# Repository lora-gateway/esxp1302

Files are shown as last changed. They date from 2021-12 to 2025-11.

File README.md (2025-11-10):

# About ESXP1302 LoRa Gateway

<p align="center">
  ESXP1302 Logo
</p>

ESXP1302 = ESP32 + SX1302.

**ESXP1302** is a low cost 8 channel LoRa gateway design, based on ESP32 platform and porting of
[SX1302\_HAL](https://github.com/Lora-net/sx1302_hal), based on the latest Version *2.1.0*.

<p align="center">
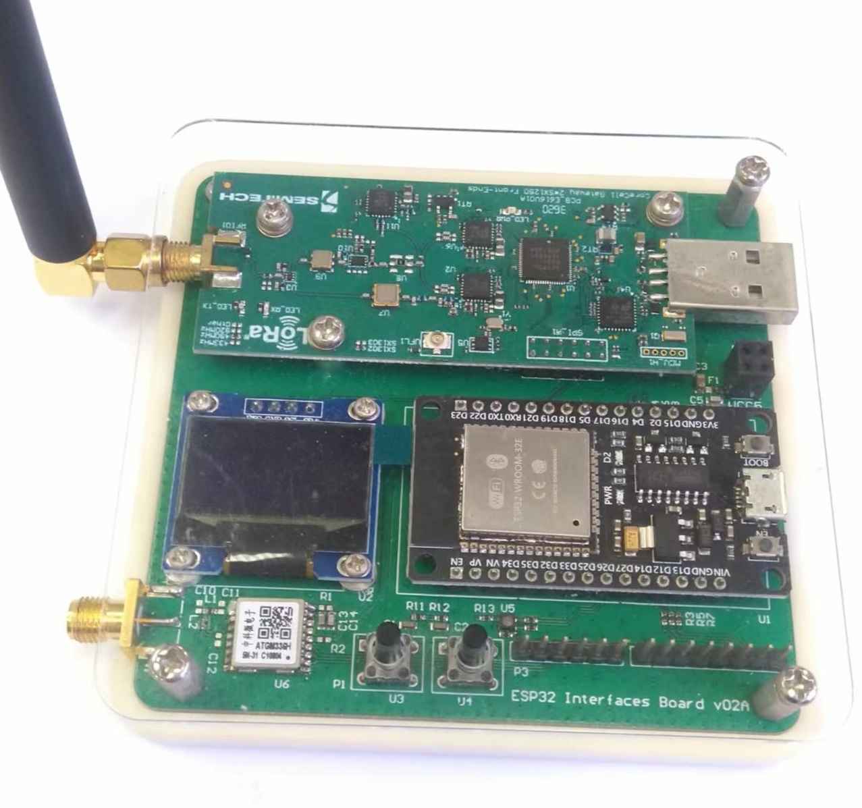
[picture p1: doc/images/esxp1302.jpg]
ESXP1302 pic
  
</p>

## How to Compile

There are two ways to compile this project.

### By PlatformIO IDE

[PlatformIO](https://platformio.org/) is a development environment that enables easy multi-platform development and centralized tooling. PlatformIO IDE bases on [Visual Studio Code](https://code.visualstudio.com/).

Follow these steps to compile ESXP1302 and flash the produced firmware.

- Clone this project with: `git clone https://github.com/lora-gateway/esxp1302`.
- Open the newly cloned folder in VS Code. If you do this for the first time, this can take quite some while as PlatformIO will download all the necessary tooling and libraries. Also if platformio is not installed, VS Code will ask you to install it.
- Open your [command palette](https://code.visualstudio.com/docs/getstarted/userinterface#_command-palette) with below shortcuts:
    - Windows/Linux: `Ctrl + Shift + P`
    - Mac: `Command + Shift + P`
- To build the firmware, simply run `PlatformIO: Build` from your command palette.
- To flash the firmware to your device, just run `PlatformIO: Upload` from your command palette.

### By Command line

You need ESP32 development environment [esp-idf](https://github.com/espressif/esp-idf).

Please follow the guide to install the SDK and the tools, or just follow below simplified steps:
```shell
git clone https://github.com/espressif/esp-idf.git
cd esp-idf
git checkout v5.5.1  # v5.4.2 also OK; other versions not verified
git submodule update --init --recursive

# below 2 steps are for Linux. For windows, use `install.bat` and `export.bat` instead.
./install.sh  # install the compilers etc.
. export.sh   # export and set up the environment
```

Then compile this project follow below steps:
```shell
git clone https://github.com/lora-gateway/esxp1302
cd esxp1302
./run_me.sh make  # compile
./run_me.sh flash_all  # flash 3 images: bootloader, partition_table and esxp1302
# ./run_me.sh flash  # use this to only flash esxp1302 firmware
```

Script `run_me.sh` can compile the code, flash the ESP32 board, and open **minicom** to monitor the output, so make sure your ESP32 board is connected.
If you are not under Linux, you need to change `run_me.sh` to use other terminal tool instead or just run your terminal tool manually.

Run `./run_me.sh -h` for its whole usage.

**Note**: a few extra steps for esp32c3 (not needed for esp32):
- run `cp sdkconfig.esp32c3 sdkconfig` before `./run_me.sh make`.
- for `./run_me.sh flash` to work, need to change `--chip esp32` to `--chip esp32c3` at line 13 in file `run_me.sh`.

## Configurations

There are 2 compile targets:
- **main/packet_forwarder/lora_pkt_fwd.c**. This is the default target.
- **main/libloragw-test/cli4test.c**. This provides a command line interface to support several test commands.

It's controlled by flag **CONFIG_LIBLORAGW_TEST**. Change the value to "1" in `run_me.sh` to switch to the second target.

## Usage

At the terminal, you should be able to input the command with your argument of option, such as:
```shell
test_loragw_hal_tx -r 1250 -c 0 -f 505.5 --pwid 22 -b 125 -n 20
test_loragw_hal_tx -r 1250 -c 0 -f 505.5 --pwid 22 -b 125 -n 20 -m CW
test_network_connection -u wireless_ssid -p wireless_password --host 192.168.1.200 --port 2000
pkt_fwd -u wireless_ssid -p wireless_password --host 192.168.1.200 --port 1680
```

Or change settings for `pkt_fwd` from browser:
<p align="center">
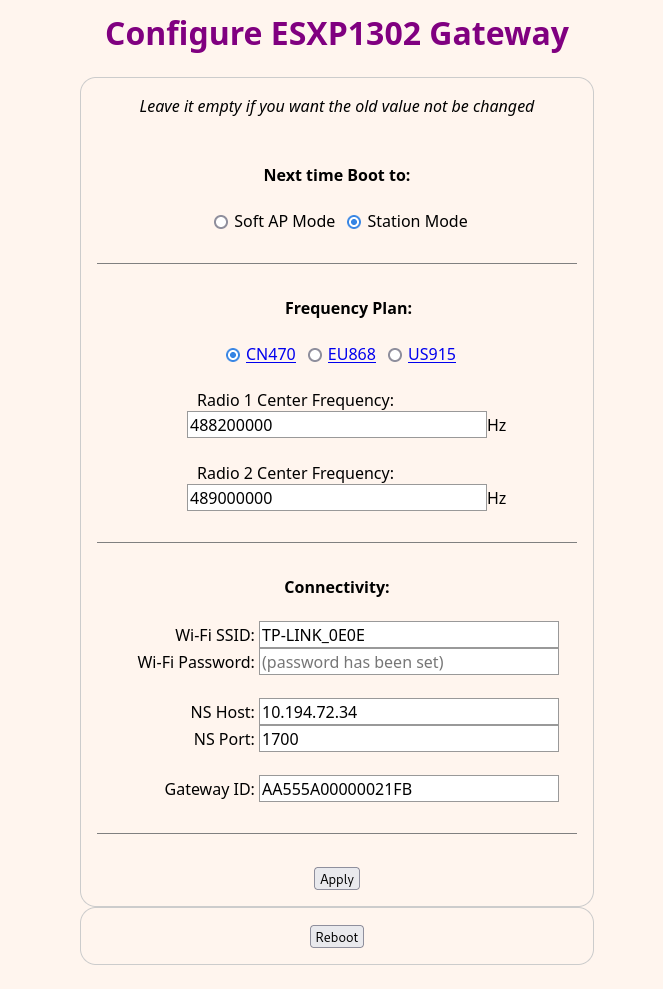
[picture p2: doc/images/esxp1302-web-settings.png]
ESXP1302 Web Settings
  
</p>

The usage details and all kinds of documents (user guide, changelog, todo list etc.) are available from `doc` folder.

## License

ESXP1302 is distributed under the 3-clause BSD license. See also [License](LICENSE.TXT).

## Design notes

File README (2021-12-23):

README

This is the ESP32 platform porting of SX1302_HAL project (https://github.com/Lora-net/sx1302_hal), based on the Version 1.0.5.
I try to stick to the original code as much as possible, but also removed some line-seperating comments I think not necessary.
And when involving ESP32 unique features, I have to invent my own way, which also imported some difference.

How to Compile

First, you need ESP32 development environment "esp-idf". You can get it from https://github.com/espressif/esp-idf.
Please follow the guide to install the SDK as well as the tools.
Below are the simplified steps for Linux platform:
```
mkdir ~/esp
cd ~/esp
git clone --recursive https://github.com/espressif/esp-idf.git
cd esp-idf
# git checkout v4.0  # optional; this is the status I used for early development
# git checkout 4a011f31  # optional; this is the status after I upgraded the esp-idf with commit '8b9050a' at 2021-12-03.
./install.sh  # install the compilers etc.
. export.sh   # export and set up the environment
```

Then you can compile this project by first change to the project folder, and use `./run_it.sh` to build and flash it.
Run `./run_it.sh -h` for its usage.
This script can compile the code, flash the ESP32 board, and open 'minicom' to monitor the output, so make sure your ESP32 board is connected.
If you are not under Linux, you need to change `run_it.sh` to use other terminal tool instead or just run your terminal tool manually.

Configurations

There are some compile targets indeed, just as under the original sx1302_hal project under "libloragw/tst/test_*".
But you have to choose only one for compilation by change the file 'main/main.c', which is a symbol link to one of test/test_* files.
The default is test/lora_pkt_fwd.c, but you can change to others such as test/test_loragw_hal_rx.c before you run 'run_it.sh'.

Usage

At the terminal, you should be able to input the command with your argument of option, such as:
```
test_loragw_hal_tx -r 1250 -c 0 -f 505.5 --pwid 22 -b 125 -n 20
test_loragw_hal_tx -r 1250 -c 0 -f 505.5 --pwid 22 -b 125 -n 20 -m CW
test_network_connection -u wireless_ssid -p wireless_password --host 192.168.1.200 --port 2000
pkt_fwd -u wireless_ssid -p wireless_password --host 192.168.1.200 --port 1680
```

Issues and TODOs

There are some issues need to be fixed, and more features under development.

Below is the list of some of them:
1. A few test targets do no work: test_loragw_cal.c, test_loragw_counter.c, test_loragw_capture_ram.c and test_loragw_gps.c.
2. GPS can output raw data with the module "ATGM336H" but hasn't been fully verified yet.
3. Configuration from web site using ESP32 Wifi as Soft AP and web server still ongoing.

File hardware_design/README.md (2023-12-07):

# Hardware Design

The hardware of ESXP1302 mainly includes 3 parts:
- SX1302 based ref design
- Motherboard connecting SX1302 and ESP32 and screen etc.
- Outside case

## SX1302 based ref design

For this part, we just re-use the ref design provided by Semtech.

It provided in this address:
    https://www.semtech.com/products/wireless-rf/lora-core/sx1302cssxxxgw1
Under "Reference Designs" --> "USB Corecell ref design for LBT Spectral Scan gateway production package for China"

The 7z file is downloaded from that place and put under "sx1302/" folder for convenient.

**Note**:
- This ref design is for CN470 frequency band. In order to support other regions, users need to modify it accordingly.
- Since esxp1302 only uses the SPI interface for communication and the USB part is not used, so such part shouldn't be soldered (which also can save some BOM cost).

## Motherboard

This is a very simple interface board used to connect other components. Besides of the SX1302 board and ESP32 board, it contains a few other parts:
- **An screen**. It is optional and used to display some helpful information (such as Wi-Fi status; NS info; time etc.).
- **A GPS chip**. This is also optional; It can provide PPS pulse which could be useful for accurate time sync, maybe can be useful for Class B (but not implemented yet).
- **2 Buttons**. They purpose of them is for choosing Wi-Fi mode when boot, and for other potential usage not implemented yet.

The design material is under "motherboard/" folder.

## Outside case

The outside case include 2 parts:
- transparent top layer
- solid white botton layer

Both parts can be 3D printed. The design material is under "case/" folder.

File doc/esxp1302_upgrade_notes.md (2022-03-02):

# Notes for ESXP1302 Gateway Upgrade

## firmware upgrade preparation

First, make sure you have `Python 3` installed in your PC. it provides the tool `pip` to install other tools.

Then you'll need `esptool` to upgrade firmware for ESXP1302. Install it with:
```shell
pip install esptool
```

If failed, try `python -m pip install esptool` or `pip3 install esptool`.

You may need `setuptools` first. You can install it with `pip install setuptools`.

Now you can check if it's ready by run `esptool.py` or `python -m esptool`.

## upgrade firmware

There are two ways to upgrade the firmware.

### Fully upgrade

You'll need to use this upgrade way if the ESP32 is never been upgraded.

Put the firmware file(s) somewhere, then run below command under that same foler for fully upgrade:
```shell
esptool.py --port /dev/ttyUSB0 --baud 921600 --chip esp32 --before default_reset --after hard_reset write_flash -z --flash_mode dio --flash_freq 40m --flash_size detect 0x10000 ESXP1302-Pkt-Fwd.bin 0x1000 bootloader.bin 0x8000 partition-table.bin
```

You may need to change the port name(`/dev/ttyUSB0`) to the right value, for example, it would be `COMx` under Windows.

### Application upgrade

The way only upgrade the Application part, mainly used to replace an older version.

The command becomes:
```shell
esptool.py --port /dev/ttyUSB0 --baud 921600 --chip esp32 --before default_reset --after hard_reset write_flash -z --flash_mode dio --flash_freq 40m --flash_size detect 0x10000 ESXP1302-Pkt-Fwd.bin
```

**Note:** If you got error as `Failed to connect to ESP32: Timed out waiting for packet header` or `Wrong boot mode detected`, then just try the upgrade command again while pressing one of the esp32's small buttons during the upgrade command running.

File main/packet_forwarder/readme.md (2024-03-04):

	 / _____)             _              | |
	( (____  _____ ____ _| |_ _____  ____| |__
	 \____ \| ___ |    (_   _) ___ |/ ___)  _ \
	 _____) ) ____| | | || |_| ____( (___| | | |
	(______/|_____)_|_|_| \__)_____)\____)_| |_|
	  (C)2019 Semtech

SX1302 packet forwarder
=======================

## 1. Introduction

The packet forwarder is a program running on the host of a Lora gateway that
forwards RF packets receive by the concentrator to a server through a IP/UDP
link, and emits RF packets that are sent by the server. It can also emit a
network-wide GPS-synchronous beacon signal used for coordinating all nodes of
the network.

To learn more about the network protocol between the gateway and the server,
please read the PROTOCOL.TXT document.

## 2. System schematic and definitions

	((( Y )))
	    |
	    |
	+- -|- - - - - - - - - - - - -+        xxxxxxxxxxxx          +--------+
	|+--+-----------+     +------+|       xx x  x     xxx        |        |
	||              |     |      ||      xx  Internet  xx        |        |
	|| Concentrator |<----+ Host |<------xx     or    xx-------->|        |
	||              | SPI |      ||      xx  Intranet  xx        | Server |
	|+--------------+     +------+|       xxxx   x   xxxx        |        |
	|   ^                    ^    |           xxxxxxxx           |        |
	|   | PPS  +-----+  NMEA |    |                              |        |
	|   +------| GPS |-------+    |                              +--------+
	|          +-----+            |
	|                             |
	|            Gateway          |
	+- - - - - - - - - - - - - - -+

Concentrator: radio RX/TX board, based on Semtech multichannel modems (SX130x),
transceivers (SX135x) and/or low-power stand-alone modems (SX127x).

Host: embedded computer on which the packet forwarder is run. Drives the
concentrator through a SPI link.

Gateway: a device composed of at least one radio concentrator, a host, some
network connection to the internet or a private network (Ethernet, 3G, Wifi,
microwave link), and optionally a GPS receiver for synchronization.

Server: an abstract computer that will process the RF packets received and
forwarded by the gateway, and issue RF packets in response that the gateway
will have to emit.

## 3. Dependencies

This program uses the Parson library (http://kgabis.github.com/parson/) by
Krzysztof Gabis for JSON parsing.
Many thanks to him for that very practical and well written library.

This program is statically linked with the libloragw Lora concentrator library.
It was tested with v1.3.0 of the library but should work with any later
version provided the API is v1 or a later backward-compatible API.
Data structures of the received packets are accessed by name (ie. not at a
binary level) so new functionalities can be added to the API without affecting
that program at all.

This program follows the v1.3 version of the gateway-to-server protocol.

The last dependency is the hardware concentrator (based on FPGA or SX130x
chips) that must be matched with the proper version of the HAL.

## 4. Usage

* Pick the global_conf.json file that fit with your platform, region and feature
need.
* Update the JSON configuration (global and local) files, as explained below.
* Run:
    ./lora_pkt_fwd -c global_conf.json

To stop the application, press Ctrl+C.
Unless it is manually stopped or encounter a critical error, the program will
run forever.

The way the program takes configuration files into account is the following:
 * if a specific configuration file is given as program argument, use the
  one specified.
 * if there is a global_conf.json parse it.

The global configuration file should be exactly the same throughout your
network, contain all global parameters (parameters for "sensor" radio
channels) and preferably default "safe" values for parameters that are
specific for each gateway (eg. specify a default MAC address).

In each configuration file, the program looks for a JSON object named
"SX130x_conf" that should contain the parameters for the Lora concentrator
board (RF channels definition, modem parameters, etc) and another JSON object
called "gateway_conf" that should contain the gateway parameters (gateway MAC
address, IP address of the server, keep-alive time, etc).

To learn more about the JSON configuration format, read the provided JSON
files and the libloragw API documentation.

Every X seconds (parameter settable in the configuration files) the program
display statistics on the RF packets received and sent, and the network
datagrams received and sent.
The program also send some statistics to the server in JSON format.

## 5. "Just-In-Time" downlink scheduling

The LoRa concentrator can have only one TX packet programmed for departure at a
time. The actual departure of a downlink packet will be done based on its
timestamp, when the concentrator internal counter reaches timestamp’s value.
The departure of a beacon will be done based on a GPS PPS event.
It may happen that, due to network variable latency, the gateway receives one
or many downlink packets from the server while a TX is already programmed in the
concentrator. The packet forwarder has to store and order incoming downlink
packets (in a queue), so that they can all be programmed in the concentrator at
the proper time and sent over the air.
Possible failures that may occur and that have to be reported to the server are:
- It is too early or too late to send a given packet
- A packet collides with another packet already queued
- A packet collides with a beacon
- TX RF parameters (frequency, power) are not supported by gateway
- Gateway’s GPS is unlocked, so cannot process Class B downlink
It is called "Just-in-Time" (JiT) scheduling, because the packet forwarder will
program a downlink or a beacon packet in the concentrator just before it has to
be sent over the air.
Another benefit of JiT is to optimize the gateway downlink capacity by avoiding
to keep the concentrator TX buffer busy for too long.

In order to achieve "Just-in-Time" scheduling, the following software elements
have been added:
- A JiT queue, with associated enqueue/peek/dequeue functions and packet
acceptance criterias. It is where downlink packets are stored, waiting to be
sent.
- A JiT thread, which regularly checks if there is a packet in the JiT queue
ready to be programmed in the concentrator, based on current concentrator
internal time.

### 5.1. Concentrator vs GPS time synchronization

There are 2 cases for which we need to convert a GPS time to concentrator
counter:
    - Class B downlink: when the “time” field of JSON “txpk” is filled instead
      of the “tmst” field, we need to be able to determine if the packet can be
      queued in JiT queue or not, based on its corresponding concentrator
      counter value.
      Note: even if a Class-B downlink is given with a GPS timestamp, the
      concentrator TX mode is configured as “TIMESTAMP”, and not “ON_GPS”. So
      at the end, it is the counter value which will be used for transmission.
    - Beacons: beacons transmission time is based on GPS clock, and the
      concentrator TX mode is configured as “ON_GPS” for accurate beacon
      transmission on GPS PPS event. In this case, the concentrator does not
      need the packet counter to be set. But, as the JiT thread decides if a
      packet has to be peeked or not, based on its concentrator counter, we need
      to have the beacon packet counter set (see next chapter for more details
      on JiT scheduling).
We also need to convert a SX1302 counter value to GPS UTC time when we receive
an uplink, in order to fill the “time” field of JSON “rxpk” structure.

### 5.2. TX scheduling

The JiT queue implemented is a static array of nodes, where each node contains:
    - the downlink packet, with its type (beacon, downlink class A, B or C)
    - a “pre delay” which depends on packet type (BEACON_GUARD, TX_START_DELAY…)
    - a “post delay” which depends on packet type (“time on air” of this packet
      computed based on its size, datarate and coderate, or BEACON_RESERVED)

Several functions are implemented to manipulate this queue or get info from it:
    - init: initialize array with default values
    - is full / is empty: gives queue status
    - enqueue: checks if the given packet can be queued or not, based on several
      criteria’s
    - peek: checks if the queue contains a packet that must be passed
      immediately to the concentrator for transmission and returns corresponding
      index if any.
    - dequeue: actually removes from the queue the packet at index given by peek
      function

The queue is always kept sorted on ascending timestamp order.

The JiT thread will regularly check in the JiT queue if there is a packet to be
sent soon.  If a packet is matching, it is dequeued and programmed in the
concentrator TX buffer.

### 5.3. Fine tuning parameters

There are few parameters of the JiT queue which could be tweaked to adapt to
different system constraints.

    - inc/jitqueue.h:
        JIT_QUEUE_MAX: The maximum number of nodes in the queue.
    - src/jitqueue.c:
        TX_JIT_DELAY: The number of milliseconds a packet is programmed in the
                      concentrator TX buffer before its actual departure time.
        TX_MARGIN_DELAY: Packet collision check margin

### 6. License

Copyright (C) 2019, SEMTECH S.A.
All rights reserved.

Redistribution and use in source and binary forms, with or without
modification, are permitted provided that the following conditions are met:

* Redistributions of source code must retain the above copyright
  notice, this list of conditions and the following disclaimer.
* Redistributions in binary form must reproduce the above copyright
  notice, this list of conditions and the following disclaimer in the
  documentation and/or other materials provided with the distribution.
* Neither the name of the Semtech corporation nor the
  names of its contributors may be used to endorse or promote products
  derived from this software without specific prior written permission.

THIS SOFTWARE IS PROVIDED BY THE COPYRIGHT HOLDERS AND CONTRIBUTORS "AS IS" AND
ANY EXPRESS OR IMPLIED WARRANTIES, INCLUDING, BUT NOT LIMITED TO, THE IMPLIED
WARRANTIES OF MERCHANTABILITY AND FITNESS FOR A PARTICULAR PURPOSE ARE
DISCLAIMED. IN NO EVENT SHALL SEMTECH S.A. BE LIABLE FOR ANY
DIRECT, INDIRECT, INCIDENTAL, SPECIAL, EXEMPLARY, OR CONSEQUENTIAL DAMAGES
(INCLUDING, BUT NOT LIMITED TO, PROCUREMENT OF SUBSTITUTE GOODS OR SERVICES;
LOSS OF USE, DATA, OR PROFITS; OR BUSINESS INTERRUPTION) HOWEVER CAUSED AND
ON ANY THEORY OF LIABILITY, WHETHER IN CONTRACT, STRICT LIABILITY, OR TORT
(INCLUDING NEGLIGENCE OR OTHERWISE) ARISING IN ANY WAY OUT OF THE USE OF THIS
SOFTWARE, EVEN IF ADVISED OF THE POSSIBILITY OF SUCH DAMAGE.

#### 7. License for Parson library

Parson ( http://kgabis.github.com/parson/ )
Copyright (C) 2012 Krzysztof Gabis

Permission is hereby granted, free of charge, to any person obtaining a copy
of this software and associated documentation files (the "Software"), to deal
in the Software without restriction, including without limitation the rights
to use, copy, modify, merge, publish, distribute, sublicense, and/or sell
copies of the Software, and to permit persons to whom the Software is
furnished to do so, subject to the following conditions:

The above copyright notice and this permission notice shall be included in
all copies or substantial portions of the Software.

THE SOFTWARE IS PROVIDED "AS IS", WITHOUT WARRANTY OF ANY KIND, EXPRESS OR
IMPLIED, INCLUDING BUT NOT LIMITED TO THE WARRANTIES OF MERCHANTABILITY,
FITNESS FOR A PARTICULAR PURPOSE AND NONINFRINGEMENT. IN NO EVENT SHALL THE
AUTHORS OR COPYRIGHT HOLDERS BE LIABLE FOR ANY CLAIM, DAMAGES OR OTHER
LIABILITY, WHETHER IN AN ACTION OF CONTRACT, TORT OR OTHERWISE, ARISING FROM,
OUT OF OR IN CONNECTION WITH THE SOFTWARE OR THE USE OR OTHER DEALINGS IN
THE SOFTWARE.

*EOF*

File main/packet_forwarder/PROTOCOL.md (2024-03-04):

	  ______                              _
	 / _____)             _              | |
	( (____  _____ ____ _| |_ _____  ____| |__
	 \____ \| ___ |    (_   _) ___ |/ ___)  _ \
	 _____) ) ____| | | || |_| ____( (___| | | |
	(______/|_____)_|_|_| \__)_____)\____)_| |_|
	  (C)2019 Semtech

Basic communication protocol between LoRa gateway and Network Server
====================================================================

## 1. Introduction

The protocol between the gateway and the server is purposefully very basic and
for demonstration purpose only, or for use on private and reliable networks.

There is no authentication of the gateway or the server, and the acknowledges
are only used for network quality assessment, not to correct UDP datagrams
losses (no retries).

## 2. System schematic and definitions

	 ((( Y )))
	     |
	     |
	+ - -|- - - - - - - - - - - - - +        xxxxxxxxxxxx          +--------+
	| +--+-----------+     +------+ |       xx x  x     xxx        |        |
	| |              |     |      | |      xx  Internet  xx        |        |
	| | Concentrator |<--->| Host |<-------xx     or    xx-------->|        |
	| |              | SPI |      | |      xx  Intranet  xx        | Server |
	| +--------------+     +------+ |       xxxx   x   xxxx        |        |
	|    ^                     ^    |           xxxxxxxx           |        |
	|    | PPS +-------+ NMEA  |    |                              |        |
	|    +-----|  GPS  |-------+    |                              +--------+
	|          | (opt) |            |
	|          +-------+            |
	|                               |
	|             Gateway           |
	+- - - - - - - - - - - - - - - -+

__Concentrator__: radio RX/TX board, based on Semtech multichannel modems
(SX130x), transceivers (SX125x) and/or low-power stand-alone modems (SX127x).

__Host__: embedded computer on which the packet forwarder is run. Drives the
concentrator through a SPI link.

__GPS__: GNSS (GPS, Galileo, GLONASS, etc) receiver with a "1 Pulse Per Second"
output and a serial link to the host to send NMEA frames containing time and
geographical coordinates data. Optional.

__Gateway__: a device composed of at least one radio concentrator, a host, some
network connection to the internet or a private network (Ethernet, 3G, Wifi,
microwave link), and optionally a GPS receiver for synchronization.

__Server__: an abstract computer that will process the RF packets received and
forwarded by the gateway, and issue RF packets in response that the gateway
will have to emit.

It is assumed that the gateway can be behind a NAT or a firewall stopping any
incoming connection.
It is assumed that the server has an static IP address (or an address solvable
through a DNS service) and is able to receive incoming connections on a
specific port.

## 3. Upstream protocol

### 3.1. Sequence diagram ###

	+---------+                                                    +---------+
	| Gateway |                                                    | Server  |
	+---------+                                                    +---------+
	     | -----------------------------------\                         |
	     |-| When 1-N RF packets are received |                         |
	     | ------------------------------------                         |
	     |                                                              |
	     | PUSH_DATA (token X, GW MAC, JSON payload)                    |
	     |------------------------------------------------------------->|
	     |                                                              |
	     |                                           PUSH_ACK (token X) |
	     |<-------------------------------------------------------------|
	     |                              ------------------------------\ |
	     |                              | process packets *after* ack |-|
	     |                              ------------------------------- |
	     |                                                              |

### 3.2. PUSH_DATA packet ###

That packet type is used by the gateway mainly to forward the RF packets
received, and associated metadata, to the server.

 Bytes  | Function
:------:|---------------------------------------------------------------------
 0      | protocol version = 2
 1-2    | random token
 3      | PUSH_DATA identifier 0x00
 4-11   | Gateway unique identifier (MAC address)
 12-end | JSON object, starting with {, ending with }, see section 4

### 3.3. PUSH_ACK packet ###

That packet type is used by the server to acknowledge immediately all the
PUSH_DATA packets received.

 Bytes  | Function
:------:|---------------------------------------------------------------------
 0      | protocol version = 2
 1-2    | same token as the PUSH_DATA packet to acknowledge
 3      | PUSH_ACK identifier 0x01

## 4. Upstream JSON data structure

The root object can contain an array named "rxpk":

``` json
{
	"rxpk":[ {...}, ...]
}
```

That array contains at least one JSON object, each object contain a RF packet
and associated metadata with the following fields:

 Name |  Type  | Function
:----:|:------:|--------------------------------------------------------------
 time | string | UTC time of pkt RX, us precision, ISO 8601 'compact' format
 tmms | number | GPS time of pkt RX, number of milliseconds since 06.Jan.1980
 tmst | number | Internal timestamp of "RX finished" event (32b unsigned)
 ftime| number | fine timestamp, number of nanoseconds since last PPS [0..999999999] (Optional)
 freq | number | RX central frequency in MHz (unsigned float, Hz precision)
 chan | number | Concentrator "IF" channel used for RX (unsigned integer)
 rfch | number | Concentrator "RF chain" used for RX (unsigned integer)
 mid  | number | Concentrator modem ID on which pkt has been received
 stat | number | CRC status: 1 = OK, -1 = fail, 0 = no CRC
 modu | string | Modulation identifier "LORA" or "FSK"
 datr | string | LoRa datarate identifier (eg. SF12BW500)
 datr | number | FSK datarate (unsigned, in bits per second)
 codr | string | LoRa ECC coding rate identifier
 rssi | number | RSSI of the channel in dBm (signed integer, 1 dB precision)
 rssis| number | RSSI of the signal in dBm (signed integer, 1 dB precision)
 lsnr | number | Lora SNR ratio in dB (signed float, 0.1 dB precision)
 foff | number | LoRa frequency offset in Hz (signed interger)
 size | number | RF packet payload size in bytes (unsigned integer)
 data | string | Base64 encoded RF packet payload, padded

Example (white-spaces, indentation and newlines added for readability):

``` json
{"rxpk":[
	{
		"tmst":3512348611,
		"time":"2020-10-01T09:30:52.592567Z",
		"tmms":1285579871592,
		"ftime":85224290,
		"chan":2,
		"rfch":0,
		"freq":866.349812,
		"mid":3,
		"stat":1,
		"modu":"LORA",
		"datr":"SF7BW125",
		"codr":"4/6",
		"rssi":-35,
		"lsnr":5.1,
		"foff":-3313,
		"size":32,
		"data":"-DS4CGaDCdG+48eJNM3Vai-zDpsR71Pn9CPA9uCON84"
	},{
		"time":"2013-03-31T16:21:17.530974Z",
		"tmst":3512348514,
		"chan":9,
		"rfch":1,
		"freq":869.1,
		"stat":1,
		"modu":"FSK",
		"datr":50000,
		"rssi":-75,
		"size":16,
		"data":"VEVTVF9QQUNLRVRfMTIzNA=="
	},{
		"time":"2013-03-31T16:21:17.532038Z",
		"tmst":3316387610,
		"chan":0,
		"rfch":0,
		"freq":863.00981,
		"stat":1,
		"modu":"LORA",
		"datr":"SF10BW125",
		"codr":"4/7",
		"rssi":-38,
		"lsnr":5.5,
		"size":32,
		"data":"ysgRl452xNLep9S1NTIg2lomKDxUgn3DJ7DE+b00Ass"
	}
]}
```

The root object can also contain an object named "stat" :

``` json
{
	"rxpk":[ {...}, ...],
	"stat":{...}
}
```

It is possible for a packet to contain no "rxpk" array but a "stat" object.

``` json
{
	"stat":{...}
}
```

That object contains the status of the gateway, with the following fields:

 Name |  Type  | Function
:----:|:------:|--------------------------------------------------------------
 time | string | UTC 'system' time of the gateway, ISO 8601 'expanded' format
 lati | number | GPS latitude of the gateway in degree (float, N is +)
 long | number | GPS latitude of the gateway in degree (float, E is +)
 alti | number | GPS altitude of the gateway in meter RX (integer)
 rxnb | number | Number of radio packets received (unsigned integer)
 rxok | number | Number of radio packets received with a valid PHY CRC
 rxfw | number | Number of radio packets forwarded (unsigned integer)
 ackr | number | Percentage of upstream datagrams that were acknowledged
 dwnb | number | Number of downlink datagrams received (unsigned integer)
 txnb | number | Number of packets emitted (unsigned integer)
 temp | number | Current temperature in degree celcius (float)

Example (white-spaces, indentation and newlines added for readability):

``` json
{"stat":{
    "time":"2014-01-12 08:59:28 GMT",
    "lati":46.24000,
    "long":3.25230,
    "alti":145,
    "rxnb":2,
    "rxok":2,
    "rxfw":2,
    "ackr":100.0,
    "dwnb":2,
    "txnb":2,
    "temp": 23.2
}}
```

## 5. Downstream protocol

### 5.1. Sequence diagram ###

	+---------+                                                    +---------+
	| Gateway |                                                    | Server  |
	+---------+                                                    +---------+
	     | -----------------------------------\                         |
	     |-| Every N seconds (keepalive time) |                         |
	     | ------------------------------------                         |
	     |                                                              |
	     | PULL_DATA (token Y, MAC@)                                    |
	     |------------------------------------------------------------->|
	     |                                                              |
	     |                                           PULL_ACK (token Y) |
	     |<-------------------------------------------------------------|
	     |                                                              |

	+---------+                                                    +---------+
	| Gateway |                                                    | Server  |
	+---------+                                                    +---------+
	     |      ------------------------------------------------------\ |
	     |      | Anytime after first PULL_DATA for each packet to TX |-|
	     |      ------------------------------------------------------- |
	     |                                                              |
	     |                            PULL_RESP (token Z, JSON payload) |
	     |<-------------------------------------------------------------|
	     |                                                              |
	     | TX_ACK (token Z, JSON payload)                               |
	     |------------------------------------------------------------->|

### 5.2. PULL_DATA packet ###

That packet type is used by the gateway to poll data from the server.

This data exchange is initialized by the gateway because it might be
impossible for the server to send packets to the gateway if the gateway is
behind a NAT.

When the gateway initialize the exchange, the network route towards the
server will open and will allow for packets to flow both directions.
The gateway must periodically send PULL_DATA packets to be sure the network
route stays open for the server to be used at any time.

 Bytes  | Function
:------:|---------------------------------------------------------------------
 0      | protocol version = 2
 1-2    | random token
 3      | PULL_DATA identifier 0x02
 4-11   | Gateway unique identifier (MAC address)

### 5.3. PULL_ACK packet ###

That packet type is used by the server to confirm that the network route is
open and that the server can send PULL_RESP packets at any time.

 Bytes  | Function
:------:|---------------------------------------------------------------------
 0      | protocol version = 2
 1-2    | same token as the PULL_DATA packet to acknowledge
 3      | PULL_ACK identifier 0x04

### 5.4. PULL_RESP packet ###

That packet type is used by the server to send RF packets and associated
metadata that will have to be emitted by the gateway.

 Bytes  | Function
:------:|---------------------------------------------------------------------
 0      | protocol version = 2
 1-2    | random token
 3      | PULL_RESP identifier 0x03
 4-end  | JSON object, starting with {, ending with }, see section 6

### 5.5. TX_ACK packet ###

That packet type is used by the gateway to send a feedback to the server
to inform if a downlink request has been accepted or rejected by the gateway.
The datagram may optionnaly contain a JSON string to give more details on
acknoledge. If no JSON is present (empty string), this means than no error
occured.

 Bytes  | Function
:------:|---------------------------------------------------------------------
 0      | protocol version = 2
 1-2    | same token as the PULL_RESP packet to acknowledge
 3      | TX_ACK identifier 0x05
 4-11   | Gateway unique identifier (MAC address)
 12-end | [optional] JSON object, starting with {, ending with }, see section 6

## 6. Downstream JSON data structure

The root object of PULL_RESP packet must contain an object named "txpk":

``` json
{
	"txpk": {...}
}
```

That object contain a RF packet to be emitted and associated metadata with the
following fields:

 Name |  Type  | Function
:----:|:------:|--------------------------------------------------------------
 imme | bool   | Send packet immediately (will ignore tmst & tmms)
 tmst | number | Send packet on a certain timestamp value (will ignore tmms)
 tmms | number | Send packet at a certain GPS time (GPS synchronization required)
 freq | number | TX central frequency in MHz (unsigned float, Hz precision)
 rfch | number | Concentrator "RF chain" used for TX (unsigned integer)
 powe | number | TX output power in dBm (unsigned integer, dBm precision)
 modu | string | Modulation identifier "LORA" or "FSK"
 datr | string | LoRa datarate identifier (eg. SF12BW500)
 datr | number | FSK datarate (unsigned, in bits per second)
 codr | string | LoRa ECC coding rate identifier
 fdev | number | FSK frequency deviation (unsigned integer, in Hz)
 ipol | bool   | Lora modulation polarization inversion
 prea | number | RF preamble size (unsigned integer)
 size | number | RF packet payload size in bytes (unsigned integer)
 data | string | Base64 encoded RF packet payload, padding optional
 ncrc | bool   | If true, disable the CRC of the physical layer (optional)
 nhdr | bool   | If true, disable the header of the physical layer (optional)

Most fields are optional.
If a field is omitted, default parameters will be used.

Examples (white-spaces, indentation and newlines added for readability):

``` json
{"txpk":{
	"imme":true,
	"freq":864.123456,
	"rfch":0,
	"powe":14,
	"modu":"LORA",
	"datr":"SF11BW125",
	"codr":"4/6",
	"ipol":false,
	"size":32,
	"data":"H3P3N2i9qc4yt7rK7ldqoeCVJGBybzPY5h1Dd7P7p8v"
}}
```

``` json
{"txpk":{
	"imme":true,
	"freq":861.3,
	"rfch":0,
	"powe":12,
	"modu":"FSK",
	"datr":50000,
	"fdev":3000,
	"size":32,
	"data":"H3P3N2i9qc4yt7rK7ldqoeCVJGBybzPY5h1Dd7P7p8v"
}}
```

In case of error or warning, the root object of TX_ACK packet must contain an
object named "txpk_ack":

``` json
{
	"txpk_ack": {...}
}
```

That object contain status information concerning the associated PULL_RESP packet.

 Name |  Type  | Function
:----:|:------:|-----------------------------------------------------------------------------------------
error | string | Indicates the type of failure that occurred for downlink request (optional)
warn  | string | Indicates that downlink request has been accepted with limitation (optional)
value | string | When a warning is raised, it gives indications about the limitation (optional)
value | number | When a warning is raised, it gives indications about the limitation (optional)

The possible values of the "error" field are:

 Value             | Definition
:-----------------:|---------------------------------------------------------------------
 TOO_LATE          | Rejected because it was already too late to program this packet for downlink
 TOO_EARLY         | Rejected because downlink packet timestamp is too much in advance
 COLLISION_PACKET  | Rejected because there was already a packet programmed in requested timeframe
 COLLISION_BEACON  | Rejected because there was already a beacon planned in requested timeframe
 TX_FREQ           | Rejected because requested frequency is not supported by TX RF chain
 GPS_UNLOCKED      | Rejected because GPS is unlocked, so GPS timestamp cannot be used

The possible values of the "warn" field are:

 Value             | Definition
:-----------------:|---------------------------------------------------------------------
 TX_POWER          | The requested power is not supported by the gateway, the power actually used is given in the value field

Examples (white-spaces, indentation and newlines added for readability):

``` json
{"txpk_ack":{
	"error":"COLLISION_PACKET"
}}
```

``` json
{"txpk_ack":{
	"warn":"TX_POWER",
    "value":20
}}
```

## 7. Revisions

### v1.6 ###
* Added "mid" field in "rxpk" for concentrator modem ID used to demodulate pkt
* Added "foff" field in "rxpk" for frequency offset measured
* Added "rssis" field in "rxpk" for signal RSSI measured.
* Added "ftime" field in "rxpk" for fine timestamping

### v1.5 ###
* Moved TX_POWER from "error" category to "warn" category in "txpk_ack" object

### v1.4 ###
* Added "tmms" field for GPS time as a monotonic number of milliseconds
ellapsed since January 6th, 1980 (GPS Epoch). No leap second.

### v1.3 ###

* Added downlink feedback from gateway to server (PULL_RESP -> TX_ACK)

### v1.2 ###

* Added value of FSK bitrate for upstream.
* Added parameters for FSK bitrate and frequency deviation for downstream.

### v1.1 ###

* Added syntax for status report JSON object on upstream.

### v1.0 ###

* Initial version.

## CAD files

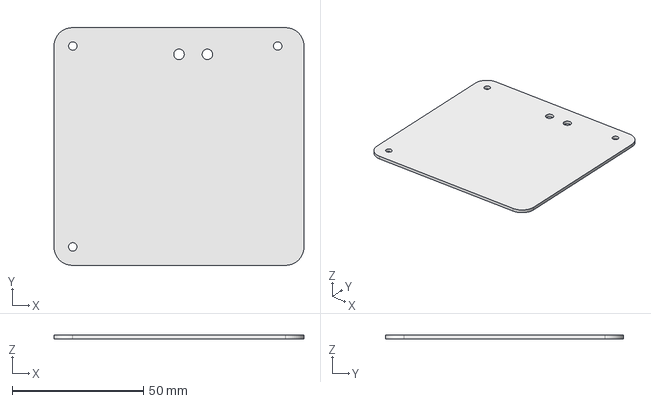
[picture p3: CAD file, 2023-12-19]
hardware_design/case/esxp1302_top_case.FCStd
95.2 x 90.5 x 1.50 mm

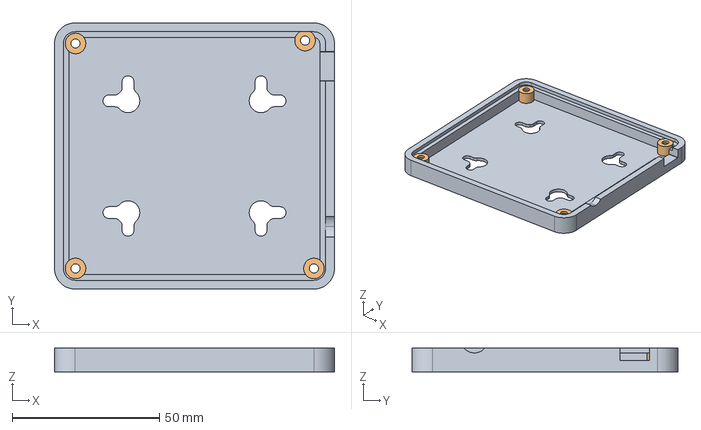
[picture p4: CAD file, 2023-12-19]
hardware_design/case/esxp1302_bottom_case.FCStd
95.2 x 90.5 x 8.00 mm
Main with Space
Columns with Holes

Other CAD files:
hardware_design/case/esxp1302_bottom_case.stl
hardware_design/case/esxp1302_top_case.dxf

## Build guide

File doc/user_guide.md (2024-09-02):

# ESXP1302 Gateway User Guide

## Basic Introduction

**ESXP1302 Gateway** project is based on `SX1302_HAL` project, but uses ESP32 instead of Raspberry Pi. *ESXP1302* = *ESP32* + *SX1302*.

This document is a very simple guide about how to configure and use ESXP1302 gateway based on **version 0.7.0**.

First, please be noted that ESXP1302 gateway has 2 types of Wi-Fi working modes, and 2 ways to configure it.

The 2 Wi-Fi modes are:
- **Soft AP** mode. The gateway works as an Wi-Fi Soft AP, so user can connect to it directly and configure it.
- **Station** mode. The gateway needs to connect to the same Wi-Fi router as the user and use that router for LoRaWAN uplink and downlink.

The 2 configuration ways are:
- **Web UI**. User can change gateway settings by browser after connect to the gateway.
- **Command line** (or Serial Port). There is a simple interactive command line interface available from the USB port, so user can configure the gateway that way without any network connection required.

## Configuration based on Wi-Fi mode

By default, the gateway boots to the Soft AP mode for the first time. It switches modes when necessary such as Wi-Fi disconnected or be controlled by user. But you can always specify which mode it boots into: just keep one of the Interface board buttons pressed during the poweron: Left button for Soft AP mode, while right button for Station mode.

In the Soft AP mode, user can connect the gateway by Wi-Fi. All the useful information can be seen from the screen, which is: `IP = "192.168.4.1"`; `username = esp32`; `password = esp32wifi`.

Now user can access the web UI by browser with address: `http://192.168.4.1`. Please be noted that the protocol is **http**, not **https**. The default login information are: `username = iot`; `password = lora`.

If the gateway boots to Station mode, then both the gateway and user needs to connect to the same wireless router. Then the only difference is user needs to get the right IP address showing on the screen or provided by the router, and access the web UI with that IP address. It **won't** be the "192.168.4.1" any more.

There are also some Wi-Fi mode automatic switch if some events happens:
- In Soft AP mode, if no changes to the web UI and no input to the command line, it reboots to Station mode in 10 minutes.
- If gateway boots to Station mode, but can't connect to wireless router (maybe wrong Wi-Fi settings or haven't set Wi-Fi yet), then it reboots to Soft AP mode in 5 minutes.
- If during the Station mode, `pkt_fwd` works all right for some time, then Wi-Fi disconnected, the gateway will try to re-connect to Wi-Fi for 5 minutes. If succeeds during that time, nothing happens; but if failed, then reboots to Soft AP mode.
- If after power on, the gateway reboots again by `brownout`, then it changes to the other mode. So user should check the screen or the command line output to be sure which mode the gateway is really in.

## Configuration by web UI

From web UI, user can configure below items:
- **next time boot into**. Generally after the configuration is done, the gateway should boot into station mode. But if the gateway will boot somewhere with some unknown Wi-Fi router and needs to provide the SSID informatioin again, then boots into Soft AP mode maybe make more sense. Consider you can always control which mode boots into by the hardware button, this option only becomes important when you can't access the gateway hardware easily.
- **Frequency Plan**. You need to choose this wisely based on your region and node settings. You can click each of them to know the details of the original JSON file used for that frequency plan.
- **Radio 1 and Radio 2 center frequency**. These 2 values should be the reasonable values based on the Frequency plan. Each control the frequency bands. The frequency bands has offsets of -300K/-100K/100K/300K Hz with the center frequency for CN470, while it's -400K/-200K/0K/200K for EU868. So please check the Frequency plan link to be sure.
- **Wi-Fi SSID and password**. Please noted that both only support the ASCII characters. It doesn't work if your SSID or password contains other UTF-8 characters such as Chinese characters. This limitation is hard to remove so you may have to change your Wi-Fi router settings.
- **NS Host and Port**. Here user needs to provide the right NS IP address (or domain name) and port.
- **Gateway ID**. Each gateway needs to have its own unique ID, so provide it here to avoid using the same one as other gateway.

If you think the original value is correct for any of above fields, then you can just leave it empty. Any value you provided would be used to replace the original one from the JSON template file.

You can save your configurations whenever you like by clicking the **Apply** button. Such changes are saved in the gateway but won't apply to the current *packet-forward* process yet. It only happens after you click the **Reboot** button to reboot the gateway, or by user reboot the gateway by power off and on.

If you don't like the default dark theme, you can try the light theme by accessing `http://<gateway_ip>/w` instead.

## Configuration by command line

If you power on the gateway by connecting the micro USB cable to a PC, then you have access to its command line interface. Use any terminal tool such as `sscom` or `putty` to access it with configuration as: **115200-8-N-1**.

The command line is the same thing as the serial port, so it outputs gateway logs. When the *packet_forward* is running, the output would mix with any characters input by user. However, if the user ignores that and continues to input or delete characters, the command line will flush itself, so it is still usable. 

When the *packet_forward* doesn't run for reasons such as when Wi-Fi is not connected, then the command line looks like a regular Linux shell interactive window; it even supports basic readline shortcuts such as `Ctrl-A` and `Ctrl-W` etc.

So far, this interface only supports one command named `pkt_fwd`. You can input `pkt_fwd -h` to learn all the options it supports, which, let's be honest, not much. It supports only parts of all the configurations available from web UI. Here is the output of `pkt_fwd -h`:
```
 ---- pkt_fwd ----

Available options:
 -h                   print this help
 -u <wifi ssid>       Wifi SSID
 -p <wifi password>   Wifi Password
 --host <NS Host>     NS Host
 --port <NS Port>     NS Port
 --gwid <gateway id>  Gateway ID
```

So, if you need to change other configuration items, please use the web UI way.

**Note:**
- Whenever you provide a valid option to `pkt_fwd`, it's saved and the gateway will reboot to apply the new changes.
- To input whitespace in command line (such as for Wi-Fi password, use `\` to escape. For example: `pkt_fwd -u mywifi -p my\ password`.

### install Windows Driver

To access the command line under Windows, users would need to install the right device driver first.

Below is the list of USB to serial converter chips installed on most of the ESP32 boards produced by Espressif together with links to the drivers:

- CP210x: [CP210x USB to UART Bridge VCP Drivers](https://www.silabs.com/developers/usb-to-uart-bridge-vcp-drivers)
- FTDI: [FTDI Virtual COM Port Drivers](https://ftdichip.com/drivers/vcp-drivers)

User can blindly install both drivers, or identifies the USB-to-UART bridge on the ESP32 board first and chooses the right one.

One way to identify the bridge under Linux is using the `lsusb` command. Run it would give output similar as **Bus 002 Device 027: ID 10c4:ea60 Silicon Labs `CP210x` UART Bridge** or **Bus 002 Device 025: ID 1a86:7523 QinHeng Electronics `CH340` serial converter**.

## Other Useful Documents

For other useful information, please refer to other documents included in the project, include the `README.md`, and a few others located in the folder `doc` including `esxp1302_upgrade_notes.md`, `notes_tips.md` and `todo_issue_list.md`.

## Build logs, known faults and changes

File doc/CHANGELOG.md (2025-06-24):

# CHANGE LOG

## v0.9.0:
- upgrade to sx1302_hal v2.1.0
- support nodo board
- add option to set NTP server address
- extends us915 TX frequency to cover the range of AS923
- allow up to 1.5MB app size
- remove black web theme
- other fixes to make esxp1302 be more flexible for different hardware designs.

## v0.8.0:
- add hardware reference design materials
- add support for esp32c3
- add support for compiling using PlatformIO
- add support for compiling under Windows (based on PlatformIO)
- optimize memory usage
- update scripts to Python3
- other fixes and document improvement

## v0.7.0:
- show version info in the screen
- change CN470 tx_freq_min from 500MHz to 470MHz for supporting RP2
- fix the bug that ns host can't be domain name
- change web username/password as 'iot/lora'
- add upgrader.py to simplify upgrade the firmware
- add license info

## v0.6.2:
- disable gps output
- workaround to support sx1303

## v0.6.1:
- hide wifi password

## v0.6.0:
- the first public released version
- add version info in the serial port output
- documents

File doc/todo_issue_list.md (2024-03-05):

# Todo List

Below are potential improvements (contributions are welcome):

- A simple online user guide (just a page linked to the web UI).
- improve the safety of Wifi by encrypting both ssid and password.
- Support user to reset both the username/password of the web UI login and for Soft AP mode.
- Reset to default: can reset the web UI and Soft AP mode username/password, as well as clean all the configs.
- Provide an online help and can be accessed from the web UI.
- Provide a way to import json file (either from web UI or some other way).
- GPS can output raw data with the module **ATGM336H** but hasn't been fully verified yet.
- Verify/update/merge test code under `main/libloragw-test/` and `main/test`.

# Issue List

Below are limitations or issues of the gateway:

- Wifi username and password only work with ASCII characters, doesn't support other UTF-8 characters.

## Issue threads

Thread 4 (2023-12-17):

Add miniPCIe interface to the board design?

danielkucera, 2023-12-17:
Hello,

I am successfully using this firmware with [LR1302 from Elecrow](https://www.elecrow.com/lr1302-lorawan-gateway-module-spi-eu868-sx1302-long-range-gateway-module-support-8-channels.html) and my [miniPCIe breakout board](https://lectronz.com/products/minipci-e-breakout-board).
This is my current setup.

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

Would you consider adding miniPCIe connector to your current HW design according to [this spec](https://www.elecrow.com/wiki/index.php?title=LR1302_LoRaWAN_Gateway_Module#Interface_Function)?
I tested the same setup also for [RAK2287](https://docs.rakwireless.com/Product-Categories/WisLink/RAK2287/Datasheet/#pinout-description) and it works .

I was considering doing it myself but I don't have the design software to edit your project and I am lazy to design it from scratch.

lora-gateway, 2023-12-18:
@danielkucera:
Thanks for this proposal. Since the market already has some miniPCIe based modules available, it would be easier for people to have the hardware ready to play with.

First, I'd like to check if all of them (or most of them) follow the same spec; then I plan to create an interface board to bridge the miniPCIe connector to the motherboard. I need help from a friend to do this, so it would take some time.

BTW: What's your design software? Is it KiCAD? Maybe in the future, someone can help to convert the hardware design to such tool so more people can modify directly...

danielkucera, 2023-12-18:
Thanks for the reply. Yes, I prefer KiCad. I even managed to import the board design and I am trying to add the interface.
This is my current WiP:
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

Maybe I can manage on my own :)

danielkucera, 2023-12-18:
> First, I'd like to check if all of them (or most of them) follow the same spec;

I believe they all come from this reference design: https://www.semtech.com/products/wireless-rf/lora-core/sx1302cssxxxgw1#documentation

dennis4lora, 2023-12-19:
Great, the design can support both kinds of interfaces, I think it's better than my idea to add a bridge board.

Still, I think there are compatibility issues needs to be noted.

First, I compared the miniPCIe Pins of RAK2287 and LR1302. Their SPI pins and a few other critical pins are the same; however, the pins for SX126x (used for LBT) doesn't match.

> I believe they all come from this reference design: https://www.semtech.com/products/wireless-rf/lora-core/sx1302cssxxxgw1#documentation

I then checked the Semtech reference design, Oops! totally different from RAK2287 and LR1302, as below:

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

Which makes me doubt if Semtech has updated the design, while RAK2287 follows an earlier one?

So I checked a few such products selling in Chinese Market:
- [product 1](https://www.ebyte.com/product-class.html?cid=1&pid=187) follows RAK2287 design, doesn't support SX126x
- [product 2](https://item.taobao.com/item.htm?spm=a21n57.1.0.0.2c35523cJPghVV&id=679597689156&ns=1&abbucket=10#detail) follows Semtech design
- [product 3](https://item.taobao.com/item.htm?spm=a21n57.1.0.0.2c35523cJPghVV&id=652728743720&ns=1&abbucket=10#detail) follows RAK2287 design, but doesn't support SX126x

**Conclusion**:
Compatibility issue does exist. If we don't need LBT (in fact ESXP1302 doesn't support it so far), then following the RAK2287 spec should support the major miniPCIe products available from market.

danielkucera, 2023-12-19:
> Oops! totally different from RAK2287 and LR1302

This completely slipped my attention, I was in the impression it is the same but you are right.

> following the RAK2287 spec should support the major miniPCIe products available from market.

I totally agree.

danielkucera, 2024-01-24:
So I had it manufactured.
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

The biggest surprise were those 0402 resistor pads - that is really something hard to assemble at home so I just bridged them with solder.

But anyway it works as expected 👌

dennis4lora, 2024-01-24:
Great, congratulations! :+1:

rwijbenga, 2024-05-31:
@danielkucera Could you share the schematic for the miniPCIe wirring to the ESP32 ?

Or the board files? :)

danielkucera, 2024-05-31:
Hi @rwijbenga ,
I don't have Altium so I just imported the board to KiCAD and botched in minipcie and wired the connections.
You can find it here:
https://github.com/danielkucera/esxp1302/tree/minipcie/hardware_design/motherboard

M10CUBE, 2024-08-20:
Hi @danielkucera
I came to your design working a LoraWAN solution from seeedstudio
https://www.seeedstudio.com/WM1302-LoRaWAN-Gateway-Module-Without-SX126-SPI-EU868-p-5847.html
I think similar to ELECROW LR1302

Our  KICAD OSHW project https://wizcube.eu project has similar PCB dimensions (90X90mm and holes 4mm from edges) a
I am thinking to make a similar design using the on board Raspberry Pico . Is that possible? I mean is any LoRaWAN software available for the RP2040 CPU?

Since our wizcube boards have already Raspberry Pi 40 pin connector I imagine a combination of:
1 - mini PCI 1302 module from seed studio or elsewhere
https://www.seeedstudio.com/WM1302-LoRaWAN-Gateway-Module-Without-SX126-SPI-EU868-p-5847.html
2 - A mini PCI HAT from seeedstudio or elsewhere. (may be found open source and manufacture our self from Gerber file)
https://www.seeedstudio.com/WM1302-Pi-Hat-p-4897.html

Plugging these 2 on any wizcube.eu module we have LoRaWAN out of the box.
So the question now is if LoRaWAN exists for Raspberry RP2040 or 2350 core?
If not plan B is to use an ESP32-C6 CPU on a raspberry Pico footprint made by Waveshare directly plugged in on a wizcube PCB. It comes cheaper that the ESP32 DEV board. Then voila! . LoRaWAN without designing any new PCB.

I would like to have your idea since we are redesigning out wizcube.eu boards correcting some issues.
If the above idea looks good we can include your comments to new design and of course everybody can benefit from our OSHW concept

I could like to have your opinion and help me on taking the right decision.
Thanks
Vasilis

danielkucera, 2024-08-21:
Hi @M10CUBE ,
LoRaWAN most likely exists for RP2040 but not with SX13xx drivers, just as client.

dennis4lora, 2024-08-21:
I agree with @danielkucera that there is no suitable sx130x project for RP2040 yet. Search on Internet, I find some results using RP2040 with LoRa as **end device**, and I'm afraid they are only based on the drivers for Rx and Tx, not even compatible with LoRaWAN protocol.

Currently, there are two LoRaWAN implementations provided by Semtech for **end device**:
- [LoRaMAC-Node](https://github.com/Lora-net/loramac-node) is deprecated
- [LBM](https://github.com/Lora-net/SWL2001) has been ported to [NRF52840](https://github.com/Lora-net/SWL2001/tree/master/lbm_applications/2_porting_nrf_52840)

but none works on Raspberry Pico.

OK, back to the **gateway** topic. 😄

This ESXP1302 project is tightly bound with ESP32 since it based on [esp-idf](https://github.com/espressif/esp-idf) using lots of services from that framework, and it also uses the Wi-Fi from ESP32 as its backhaul. Which means you can't replace ESP32 with another MCU and expect the firmware still works.

But if you only use ESP32-C6 to replace the original ESP32 MCU, I expect there would just need very trivial changes to make it working. You may find #23 is interesting.

M10CUBE, 2024-08-21:
Thanks ,
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
OK time to forget RP2040 at the moment as being LoRaWAN device. Lets move on
> OK, back to the **gateway** topic. 😄
> This ESXP1302 project is tightly bound with ESP32 since it based on [esp-idf](https://github.com/espressif/esp-idf) using lots of services from that framework, and it also uses the Wi-Fi from ESP32 as its backhaul. Which means you can't replace ESP32 with another MCU and expect the firmware still works.
You may find #23 is interesting.
>
The #23 is fantastic. I will get one. I have XIAO ESP32-C6 in the LAB.

> But if you only use ESP32-C6 to replace the original ESP32 MCU, I expect there would just need very trivial changes to make it working.
>
I  absolutely agree and the solution looks one way road:

To try the above since it does not cost me any KiCAD time. Maybe some simple wiring under the board
I also asked here and apply it to project ARGO (nRF9151) .
https://github.com/craigpeacock/Zephyr_LoRaWAN/issues/2#issue-2477758665

I think Zephyr is the keyword.
If the chip supports Zephyr you have tons of drivers out of the box. That is the case with Nordic chips.
As you Know Arduino is moving to Zephyr now.

dennis4lora, 2024-08-22:
@HeadBoffin:

You are right, thanks for pointing out those 2 projects, which are both work on Raspberry Pico as LoRaWAN client.

As for Arduino, I guess it doesn't matter whether it uses Zephyr not. And for ESXP1302, it's based on `esp-idf` which bases on FreeRTOS, so it's hard to switch to Arduino or Zephyr...

dennis4lora, 2024-08-22:
@HeadBoffin:

You are right, thanks for pointing out those 2 projects, which are both work on Raspberry Pico as LoRaWAN client.

As for Arduino, I guess it doesn't matter whether it uses Zephyr not. And for ESXP1302, it's based on `esp-idf` which bases on FreeRTOS, so it's hard to switch to Arduino or Zephyr...

PureTek-Innovations, 2024-09-03:
Lilygo now sells an ESP32 with an optional PCIe adapter
https://www.lilygo.cc/products/t-eth-elite-1?variant=44498204983477

They also have a very similar codebase with working ethernet
https://github.com/Xinyuan-LilyGO/LilyGO-ETH-Gateway

I've ordered a set to try.

danielkucera, 2024-09-03:
They even have the same typos in the code:
```
static int dns_loopup
```

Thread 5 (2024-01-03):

compilation terminated

DanielCao0, 2024-01-03:
Compiling .pio\build\esp32dev\main\loragw_debug.o
main/http_server.c:28:10: fatal error: webpage.h: No such file or directory

*****************************************************************
* Looking for webpage.h dependency? Check our library registry!
*
* CLI  > platformio lib search "header:webpage.h"
* Web  > https://registry.platformio.org/search?q=header:webpage.h
*
*****************************************************************

 #include "webpage.h"
          ^~~~~~~~~~~
compilation terminated.
*** [.pio\build\esp32dev\main\http_server.o] Error 1

danielkucera, 2024-01-03:
did you make some changes?
It works for me with latest main branch.

dennis4lora, 2024-01-03:
@DanielCao0 :
This error happens because the file **webpage.h** is dumped from file **main/webpage.html** by script **scripts/dump_html.py** happens in step `./run_me.sh make`. Since the PlatformIO way skips this step, this error shows.

The **temporal solution** is just run `./run_me.sh make` first and ignore the errors, then back to the PlatformIO way.

Still, a rightly solution is needed. 😄

BTW: the format of **webpage.h** is not as I expected, also needs to be fixed...

dennis4lora, 2024-01-03:
Should be fixed now in the **main** branch with below 2 commits:
- [update scripts to Python3](# 40f01e6)
- [keep dumped head files](# 02a41e7)

Please check. Thanks for reporting this.

DanielCao0, 2024-01-03:
Problem solved, thank you very much

DanielCao0, 2024-01-03:
Linking .pio\build\esp32dev\firmware.elf
c:/users/daniel/.platformio/packages/toolchain-xtensa-esp32/bin/../lib/gcc/xtensa-esp32-elf/8.4.0/../../../../xtensa-esp32-elf/bin/ld.exe: .pio\build\esp32dev\esp-idf\freertos\libfreertos.a(port_common.o):(.literal.main_task+0x1c): undefined reference to `app_main'
c:/users/daniel/.platformio/packages/toolchain-xtensa-esp32/bin/../lib/gcc/xtensa-esp32-elf/8.4.0/../../../../xtensa-esp32-elf/bin/ld.exe: .pio\build\esp32dev\esp-idf\freertos\libfreertos.a(port_common.o): in function `main_task':
C:\Users\daniel\.platformio\packages\framework-espidf\components\freertos\port/port_common.c:135: undefined reference to `app_main'
collect2.exe: error: ld returned 1 exit status
*** [.pio\build\esp32dev\firmware.elf] Error 1
================================================================================================================ [FAILED] Took 269.64 seconds ================================================================================================================
 *  The terminal process "C:\Users\daniel\.platformio\penv\Scripts\platformio.exe 'run'" terminated with exit code: 1.
 *  Terminal will be reused by tasks, press any key to close it.

dennis4lora, 2024-01-04:
I never compiled it under Windows. However, I have a guess about the reason of this error.

In fact, **main/main.c** is a soft link to **main/lora_pkt_fwd.c** under Linux. Under Windows, maybe this link is broken. If so, then just rename **main/lora_pkt_fwd.c** to **main/main.c** should fix it.

dennis4lora, 2024-01-04:
I just cloned the code in Windows, and found both link files (**sdkconfig.esp32dev** and **main/main.c**) become normal files whose contents are the linked file names (or empty files if download the code as a zip file), which cause problem.

@DanielCao0 How did you deal with file **sdkconfig.esp32dev**? Do you just copied **sdkconfig**?

One potential solution is using hard link instead, which I guess should work on both Linux and Windows; but I need to check first.

DanielCao0, 2024-01-04:
Processing esp32dev (platform: espressif32@5.4.0; framework: espidf; board: esp32dev)
----------------------------------------------------------------------------------------------------------------------------------------------------------------------------------------Verbose mode can be enabled via `-v, --verbose` option
CONFIGURATION: https://docs.platformio.org/page/boards/espressif32/esp32dev.html
PLATFORM: Espressif 32 (5.4.0) > Espressif ESP32 Dev Module
HARDWARE: ESP32 240MHz, 320KB RAM, 4MB Flash
DEBUG: Current (cmsis-dap) External (cmsis-dap, esp-bridge, esp-prog, iot-bus-jtag, jlink, minimodule, olimex-arm-usb-ocd, olimex-arm-usb-ocd-h, olimex-arm-usb-tiny-h, olimex-jtag-tiny, tumpa)
PACKAGES:
 - framework-espidf @ 3.40405.230623 (4.4.5)
 - tool-cmake @ 3.16.4
 - tool-esptoolpy @ 1.40400.0 (4.4.0)
 - tool-idf @ 1.0.1
 - tool-mconf @ 1.4060000.20190628 (406.0.0)
 - tool-ninja @ 1.9.0
 - toolchain-esp32ulp @ 1.23500.220830 (2.35.0)
 - toolchain-xtensa-esp32 @ 8.4.0+2021r2-patch5
Reading CMake configuration...
Generating assembly for certificate bundle...
LDF: Library Dependency Finder -> https://bit.ly/configure-pio-ldf
LDF Modes: Finder ~ chain, Compatibility ~ soft
Found 0 compatible libraries
Scanning dependencies...
No dependencies
Building in release mode
Compiling .pio\build\esp32dev\main\main.o
Compiling .pio\build\esp32dev\main\base64.o
main/main.c:1:13: error: expected '=', ',', ';', 'asm' or '__attribute__' before '.' token
 lora_pkt_fwd.c
             ^
Compiling .pio\build\esp32dev\main\ioe.o
Compiling .pio\build\esp32dev\main\http_server.o
Compiling .pio\build\esp32dev\main\jitqueue.o
Compiling .pio\build\esp32dev\main\loragw_aux.o
Compiling .pio\build\esp32dev\main\loragw_cal.o
Compiling .pio\build\esp32dev\main\loragw_debug.o
*** [.pio\build\esp32dev\main\main.o] Error 1
============================================================================= [FAILED] Took 21.08 seconds =============================================================================

 *  The terminal process "C:\Users\daniel\.platformio\penv\Scripts\platformio.exe 'run'" terminated with exit code: 1.
 *  Terminal will be reused by tasks, press any key to close it.

DanielCao0, 2024-01-04:
This is what I just cloned and compiled using vscode+platform+windows ....

DanielCao0, 2024-01-04:
[platformio]
src_dir = main

[env:esp32dev]
platform = espressif32@5.4.0
framework = espidf
board = esp32dev
monitor_speed = 115200

dennis4lora, 2024-01-04:
Can you just rename or copy **main/lora_pkt_fwd.c** to **main/main.c** and compile again?

DanielCao0, 2024-01-04:
esptool.py v4.4
Creating esp32 image...
Merged 1 ELF section
Successfully created esp32 image.
Linking .pio\build\esp32dev\firmware.elf
c:/users/daniel/.platformio/packages/toolchain-xtensa-esp32/bin/../lib/gcc/xtensa-esp32-elf/8.4.0/../../../../xtensa-esp32-elf/bin/ld.exe: .pio\build\esp32dev\main\main.o:(.literal.esp_print_tasks+0x10): undefined reference to `vTaskList'
c:/users/daniel/.platformio/packages/toolchain-xtensa-esp32/bin/../lib/gcc/xtensa-esp32-elf/8.4.0/../../../../xtensa-esp32-elf/bin/ld.exe: .pio\build\esp32dev\main\main.o: in function
`esp_print_tasks':
E:\esp32_gateway\esxp1302/main/main.c:1316: undefined reference to `vTaskList'
collect2.exe: error: ld returned 1 exit status
*** [.pio\build\esp32dev\firmware.elf] Error 1
============================================================================= [FAILED] Took 265.19 seconds =============================================================================
 *  The terminal process "C:\Users\daniel\.platformio\penv\Scripts\platformio.exe 'run'" terminated with exit code: 1.
 *  Terminal will be reused by tasks, press any key to close it.

dennis4lora, 2024-01-04:
I just add a commit: [change soft link to hard link to support Windows PlatformIO compile](https://github.com/lora-gateway/esxp1302/commit/ccdfde4b6cb3da2fe38fd6fd8d2d5f01fa5738e5); now the build step works all right in my Windows.

Can you pull it and try again?

DanielCao0, 2024-01-04:
Thank you.

esptool.py v4.4
Creating esp32 image...
Merged 1 ELF section
Successfully created esp32 image.
Linking .pio\build\esp32dev\firmware.elf
Retrieving maximum program size .pio\build\esp32dev\firmware.elf
Checking size .pio\build\esp32dev\firmware.elf
Advanced Memory Usage is available via "PlatformIO Home > Project Inspect"
RAM:   [=====     ]  47.9% (used 156904 bytes from 327680 bytes)
Flash: [========= ]  89.5% (used 938229 bytes from 1048576 bytes)
Building .pio\build\esp32dev\firmware.bin
esptool.py v4.4
Creating esp32 image...
Merged 25 ELF sections
Successfully created esp32 image.

lora-gateway, 2024-01-05:
Thanks @danielkucera for providing a better solution (https://github.com/lora-gateway/esxp1302/commit/1ee2ffe5b9c325d68ae35936873ddad9786d5f56) than the hard link way.
And I'm sure this issue can be closed. 😃

Closed 2024-01-05.

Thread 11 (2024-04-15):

about "webpage.html" how to convert to "webpage.h"

majorzpley, 2024-04-15:
Hello,
  I am using ur code trying to run on ESP32 DEVKIT_C board,it works great!I was planning to make some changes to the web page"webpage.html".After I modified this web page file<webpage.html>,I cleared the contents of the <webpage.h> file,then i try with "./run_me.sh make",however，There is nothing in the webpage.h file.It seems that there is something wired with the "scripts/dump_html.py" file.i am unfamiliar with Python,plz help me get over it,this is my virtual mathine configurations:
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

danielkucera, 2024-04-16:
Hi @majorzpley ,

can you post the output of the script you run?

majorzpley, 2024-04-16:
Hello @danielkucera,

1、This is ". export.sh" under file "esp-idf" output:

**majorzpley@ubuntu:~/esp-idf$ . export.sh

Setting IDF_PATH to '/home/majorzpley/esp-idf'
Detecting the Python interpreter
Checking "python" ...
Command 'python' not found, did you mean:
  command 'python3' from deb python3
  command 'python' from deb python-is-python3
Checking "python3" ...
Python 3.8.10
"python3" has been detected
Adding ESP-IDF tools to PATH...
Using Python interpreter in /home/majorzpley/.espressif/python_env/idf4.4_py3.8_env/bin/python
Checking if Python packages are up to date...
/home/majorzpley/esp-idf/tools/check_python_dependencies.py:12: DeprecationWarning: pkg_resources is deprecated as an API. See https://setuptools.pypa.io/en/latest/pkg_resources.html
  import pkg_resources
Python requirements from /home/majorzpley/esp-idf/requirements.txt are satisfied.
Added the following directories to PATH:
  /home/majorzpley/esp-idf/components/esptool_py/esptool
  /home/majorzpley/esp-idf/components/espcoredump
  /home/majorzpley/esp-idf/components/partition_table
  /home/majorzpley/esp-idf/components/app_update
  /home/majorzpley/.espressif/tools/xtensa-esp-elf-gdb/11.2_20220823/xtensa-esp-elf-gdb/bin
  /home/majorzpley/.espressif/tools/riscv32-esp-elf-gdb/11.2_20220823/riscv32-esp-elf-gdb/bin
  /home/majorzpley/.espressif/tools/xtensa-esp32-elf/esp-2021r2-patch5-8.4.0/xtensa-esp32-elf/bin
  /home/majorzpley/.espressif/tools/xtensa-esp32s2-elf/esp-2021r2-patch5-8.4.0/xtensa-esp32s2-elf/bin
  /home/majorzpley/.espressif/tools/xtensa-esp32s3-elf/esp-2021r2-patch5-8.4.0/xtensa-esp32s3-elf/bin
  /home/majorzpley/.espressif/tools/riscv32-esp-elf/esp-2021r2-patch5-8.4.0/riscv32-esp-elf/bin
  /home/majorzpley/.espressif/tools/esp32ulp-elf/2.35_20220830/esp32ulp-elf/bin
  /home/majorzpley/.espressif/tools/openocd-esp32/v0.11.0-esp32-20221026/openocd-esp32/bin
  /home/majorzpley/.espressif/python_env/idf4.4_py3.8_env/bin
  /home/majorzpley/esp-idf/tools
Done! You can now compile ESP-IDF projects.
Go to the project directory and run:

  idf.py build

/home/majorzpley/esp-idf/tools/check_python_dependencies.py:12: DeprecationWarning: pkg_resources is deprecated as an API. See https://setuptools.pypa.io/en/latest/pkg_resources.html
  import pkg_resources**

2、This the output of the script "./runme.sh make":

**majorzpley@ubuntu:/mnt/hgfs/shared/esxp1302_debug$ ./run_me.sh make
/home/majorzpley/esp-idf/tools/check_python_dependencies.py:12: DeprecationWarning: pkg_resources is deprecated as an API. See https://setuptools.pypa.io/en/latest/pkg_resources.html
  import pkg_resources
Executing action: app
Running make in directory /mnt/hgfs/shared/esxp1302_debug/build
Executing "make -j 4 app"...
[  0%] Built target custom_bundle
[  1%] Built target partition_table_bin
[  1%] Built target _project_elf_src
[  1%] Built target memory_ld
[  1%] Built target __idf_ulp
[  1%] Built target __idf_esp_serial_slave_link
[  1%] Built target __idf_sdmmc
[  1%] Built target __idf_esp_https_ota
[  2%] Built target __idf_esp_http_server
[  2%] Built target __idf_esp_http_client
[  3%] Built target __idf_tcp_transport
[  3%] Built target __idf_esp-tls
[  6%] Built target __idf_nghttp
[  6%] Built target __idf_app_trace
[  6%] Built target __idf_cxx
[  7%] Built target __idf_newlib
[  8%] Built target __idf_freertos
[  8%] Built target __idf_esp_timer
[  8%] Built target __idf_esp_common
[  9%] Built target __idf_xtensa
[ 12%] Built target __idf_esp_hw_support
[ 14%] Built target __idf_soc
[ 15%] Built target __idf_heap
[ 15%] Built target __idf_log
[ 23%] Built target __idf_lwip
[ 25%] Built target __idf_console
[ 25%] Built target __idf_esp_wifi
[ 31%] Built target __idf_wpa_supplicant
[ 32%] Built target __idf_esp_event
[ 32%] Built target __idf_esp_netif
[ 32%] Built target __idf_tcpip_adapter
[ 33%] Built target __idf_esp_eth
[ 34%] Built target __idf_vfs
[ 38%] Built target __idf_hal
[ 39%] Built target __idf_esp_rom
[ 42%] Built target __idf_esp_system
[ 43%] Built target __idf_esp_phy
[ 44%] Built target __idf_espcoredump
[ 44%] Built target __idf_esp_gdbstub
[ 45%] Built target __idf_pthread
[ 46%] Built target __idf_nvs_flash
[ 48%] Built target __idf_spi_flash
[ 49%] Built target __idf_bootloader_support
[ 50%] Built target __idf_app_update
[ 58%] Built target mbedcrypto
[ 59%] Built target mbedx509
[ 60%] Built target mbedtls
[ 60%] Built target __idf_mbedtls
[ 60%] Built target __idf_esp_pm
[ 63%] Built target __idf_driver
[ 63%] Built target __idf_esp_ipc
[ 64%] Built target __idf_efuse
[ 64%] Built target __idf_esp_ringbuf
[ 65%] Built target __idf_json
[ 65%] Built target __idf_protobuf-c
[ 65%] Built target __idf_mdns
[ 65%] Built target __idf_asio
[ 66%] Built target __idf_cbor
[ 66%] Built target __idf_unity
[ 66%] Built target __idf_esp_adc_cal
[ 69%] Built target __idf_coap
[ 70%] Built target __idf_esp_hid
[ 71%] Built target __idf_esp_lcd
[ 72%] Built target __idf_esp_websocket_client
[ 73%] Built target __idf_expat
[ 74%] Built target __idf_wear_levelling
[ 74%] Built target __idf_jsmn
[ 77%] Built target __idf_mqtt
[ 79%] Built target __idf_freemodbus
[ 80%] Built target __idf_openssl
[ 90%] Built target __idf_libsodium
[ 90%] Built target __idf_perfmon
[ 91%] Built target __idf_spiffs
[ 92%] Built target __idf_protocomm
[ 92%] Built target __idf_cmock
[ 93%] Built target __idf_fatfs
[ 94%] Built target __idf_esp_local_ctrl
[ 95%] Built target __idf_wifi_provisioning
Scanning dependencies of target __idf_main
[ 95%] Building C object esp-idf/main/CMakeFiles/__idf_main.dir/packet_forwarder/lora_pkt_fwd.c.obj
[ 95%] Building C object esp-idf/main/CMakeFiles/__idf_main.dir/packet_forwarder/http_server.c.obj
/mnt/hgfs/shared/esxp1302_debug/main/packet_forwarder/lora_pkt_fwd.c: In function 'start_reboot_timer_ms':
/mnt/hgfs/shared/esxp1302_debug/main/packet_forwarder/lora_pkt_fwd.c:3912:25: warning: initialization of 'void (*)(void *)' from incompatible pointer type 'void (*)(void)' [-Wincompatible-pointer-types]
             .callback = &reboot_timer_callback,
                         ^
/mnt/hgfs/shared/esxp1302_debug/main/packet_forwarder/lora_pkt_fwd.c:3912:25: note: (near initialization for 'reboot_timer_args.callback')
[ 96%] Linking C static library libmain.a
[100%] Built target __idf_main
[100%] Generating ld/sections.ld
[100%] Built target __ldgen_output_sections.ld
[100%] Linking CXX executable ESXP1302-Pkt-Fwd.elf
[100%] Built target ESXP1302-Pkt-Fwd.elf
make[3]: Warning: File 'ESXP1302-Pkt-Fwd.elf' has modification time 0.13 s in the future
[100%] Generating binary image from built executable
esptool.py v3.3.4-dev
Creating esp32 image...
Merged 25 ELF sections
Successfully created esp32 image.
Generated /mnt/hgfs/shared/esxp1302_debug/build/ESXP1302-Pkt-Fwd.bin
make[3]: warning:  Clock skew detected.  Your build may be incomplete.
[100%] Built target gen_project_binary
ESXP1302-Pkt-Fwd.bin binary size 0xfa080 bytes. Smallest app partition is 0x100000 bytes. 0x5f80 bytes (2%) free.
[100%] Built target app_check_size
[100%] Built target app

App build complete. To flash, run this command:
/home/majorzpley/.espressif/python_env/idf4.4_py3.8_env/bin/python ../../../../home/majorzpley/esp-idf/components/esptool_py/esptool/esptool.py -p (PORT) -b 460800 --before default_reset --after hard_reset --chip esp32  write_flash 0x10000 build/ESXP1302-Pkt-Fwd.bin
or run 'idf.py -p (PORT) app-flash'**

dennis4lora, 2024-04-18:
In earlier versions (such as v0.8), `run_me.sh` does produce **main/webpage.h**; but now that file is moved to folder `main/packet_forwarder` instead, where is more reasonable.

Sorry for the confusion. It's my fault not removing the old one from the code in time. I'll fix it soon.

BTW: I'll also remove the black web theme to avoid the duplication and save some space.

majorzpley, 2024-04-18:
@dennis4lora

thanks a lot!This question has been bothering me for a long time.

dennis4lora, 2024-04-18:
@majorzpley You are welcome, and sorry for not answering it in time. :smile:

I've made a [commit](https://github.com/lora-gateway/esxp1302/commit/ca09ffec99201f84c28cfe5d63a6aa3afdfe8bf6) to address above issue.

I guess you can close this issue if you see no further problem anymore. Thanks.

majorzpley, 2024-04-19:
@dennis4lora
ok,I'll verify it as soon as possible.

majorzpley, 2024-04-19:
@dennis4lora
i have already test the script on my machine,it works fine,thanks a lot.👍

valcarcexyz, 2024-05-25:
This should also be generated when using PlatformIO or it won't compile

Closed 2024-04-19.

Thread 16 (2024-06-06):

Tasmota integration with esxp1302?

michcfr, 2024-06-06:
Hello,
I would like to integrate the esxp1302 code with Tasmota to take the benefits of sending any data over MQTT with 8-channel LORA.
Tasmota has already this capability, named bridge, but for single channel devices with the SX126x or SX127x. See https://tasmota.github.io/docs/LoRa-and-LoRaWan-Bridge/

Do you have an idea of how to handle it? or at least any chance to get it for next versions/evolutions?
Please provide any feedbacks. Thank you.

Michel

dennis4lora, 2024-06-08:
Thanks for this proposal. I don't object it but I also don't think it's easy to add MQTT support.

I have a quick check the LoRaWAN Bridge support provided by Tasmota. The reason why it only supports single channel is because all the LoRa chips it supports are node chips, while SX1302 and SX1303 are gateway chips. They have different drivers and functions, so Tasmota can't add support to sx1302 by re-using its current code for sx127x/sx126x.

In fact, if external bridge is OK for you, then one is already available: https://github.com/chirpstack/chirpstack-gateway-bridge.

And if you would like esxp1302 itself to support MQTT, then we can have more discuss about how it should be like and how to implement it and if it's reasonable and doable...  :smile:

michcfr, 2024-06-08:
Thank you for your response.

From the end user point of view, it is useful to have Lora to MQTT directly supported by the ESP32 rather than an external bridge:
-no need of external PC, the ESP32 device acts like a MQTT hub
-take the benefit of the Tasmota ecosystem: user interface, update, community...
-have mechanisms of device/sensor plugin by specifying mapping on a per-device type basis. see Zigbee2MQTT

I'm not a LORA specialist, but my idea is to add into your code some code written for the ESP32 that supports:
-LoraBridge: gateway Bridge as done by the ChirpStack Gateway Bridge but embedded into the ESP32
-Lora2MQTT: transform Lora packets into MQTT messages embedded into the ESP32. Tasmota did it for ZigBee by writting Zigbee2Tasmota (Z2T), inspired by Zigbee2MQTT (https://www.zigbee2mqtt.io/)

Of course, your would let the user to use the device as LoRaWAN gateway, or as MQTT bridge.

Please tell me if I am clear...or not :-)

dennis4lora, 2024-06-11:
I'm not familiar with Tasmota, so I'm afraid I can't help to make esxp1302 to be a bridge in Tasmota.
However, if just to add MQTT support in esxp1302, I think it's doable.

If I'm right, then what you want esxp1302 to become should be like this:

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

If so, then there are two things to do:
- add a thread for MQTT support
- add a switch to control if ESXP1302 traffic goes to LoRaWAN NS or goes through the MQTT bridge to MQTT server.

michcfr, 2024-06-11:
Thank you.
Yes, this is what I need for the MQTT bridge :-)

I would go further since I need to get a full autonomous bridge, the same way as Tasmota did for ZigBee. The features I would like to get implemented in the Bridge would be:

1)MQTT bridge as you mention in the figure.
I also need to use MQTT for controlling the ESXP1302 bridge, as done in: www.zigbee2mqtt.io/guide/usage/mqtt_topics_and_messages.html. For example, for pairing LORA Devices with the Bridge through MQTT. Tasmota for ZigBee was inspired from Zigbee2mqtt.

2)add Ethernet support to ESXP1302 by interfacing with an ethernet chip like LAN8720 or W5500 so that it can be connected to an ethernet router:
SX1302 <=> ESP32 <=> Ethernet chip <=> Ethernet router

3)Various WebUI for ESXP1302 configuration:
.ESXP1302 acts as a WiFi AP configuration to be configured like: tasmota.github.io/docs/Getting-Started/#__tabbed_2_2
.MQTT configuration: tasmota.github.io/docs/MQTT/#configure-mqtt
.Joint procedure: to allow devices to join the network Permit Join button in the WebUI

Please give me your feedbacks. What can be done or not.

Thank you

danielkucera, 2024-06-11:
Adding ethernet should be pretty easy, esp-idf has drivers.
https://github.com/espressif/esp-idf/tree/v5.2.2/examples/ethernet/basic

michcfr, 2024-06-11:
Thank you Daniel,
Good to know that this lib can do 2) but how to integrate it in the esxp1302?

I also found this lib: https://docs.openmqttgateway.com
It can do 1) MQTT bridge + 3)WebUI

Controlling the ESXP1302 bridge as mentionned in 1) we can put placeholders in the code to read the Lora payload and interpret it. Some solution propose  Yaml to interpret the message.

dennis4lora, 2024-06-12:
My opinions:

Currently esxp1302 has a simple web page for settings (I just updated the README to include it). Of course it's useful if it supports other ways such as use web API (though not available so far) or by MQTT. And I guess either YAML or JSON (esxp1302 contains a small library for it) should be OK. But you'll need to define what items for customizing.

For your #3:
- esxp1302 can work as either a Soft AP or station, and be controlled by web settings.
- The join procedure is handled by LoRaWAN protocol and user registers devices on NS (Network Server). I don't think it makes sense to do it on the gateway side. I would use MQTT for simple applications (such as receive uplink packets), and use NS such as Chirpstack for complex functions. But I maybe wrong. :-)

For Ethernet support:
- If you want to replace Wi-Fi with Ethernet interface, I think it would be easy: just check how it's be done in the original [sx1302_hal](https://github.com/Lora-net/sx1302_hal) and use it as a guide to replace the Wi-Fi related code.
- If you want to have both Wi-Fi and Ethernet co-exist, it's much complex. For example: how to decide which interface be used for connecting to NS?

So I suggest that you pick the 1st way to start with.

I'm not sure if `openmqttgateway` could be re-used or not...

Here are some simple MQTT examples provided by esp-idf: https://github.com/espressif/esp-idf/tree/v5.2.2/examples/protocols/mqtt

michcfr, 2024-06-14:
Thank you for your response.

-ok for the simple web page for settings, soft AP/station and for controlling.
-I want to replace Wifi with Ethernet. It is exclusive: I don't need both at the same time.
-I can start with the simple MQTT examples you provide.

Concerning the NS, the theory I want to experiment is that for simple applications, we can avoid it by using few simple MQTT commands. The ESXP1302 would acts as micro-NS based on MQTT.

Would you mind to update the ESXP1302 code to support the Ethernet and the simple MQTT bridge?
It will be very helpfull for me as a starting point.

dennis4lora, 2024-06-17:
> Would you mind to update the ESXP1302 code to support the Ethernet and the simple MQTT bridge?

I have no Ethernet hardware currently, so I would work on the MQTT bridge support first.

**BTW**: if you make Ethernet exclusive, then you won't need to support soft AP/station switch anymore...

michcfr, 2024-06-17:
Great! Thank you Dennis

Can you please put a placeholder (callback for example) before the Esp32 sends the MQTT message to the MQTT broker?
To do some processing on the message before it is sent to the MQTT broker.

Yes, if Ethernet is choosen then AP is not needed.
I still would need AP at the initialisation phase to set the Ethernet IP address (fixed or DHCP) and eventually MQTT parameters. It can be useful for some situations where I lost contact with the Ethernet: at reset, the esxp1302 will be reachable as wifi AP.

I have other questions not related to this topic but I don't know if I have to create separate topics. It is about:
-how to manage the duty cycle?
-is the sx1303 supported?

dennis4lora, 2024-06-17:
I propose that I just work on sending the original JSON message to MQTT broker as the default behavior, then you can customize this to suit your specific requirements, which should be very easy: you can add callback or do changes in the thread directly.

If your Ethernet connects to a Router which provides DHCP service, then the wireless interface is not necessary and the logic would be simpler. To provide option for both DHCP and fixed IP, then Wi-Fi is needed.

For your two questions:
- Duty cycle is handled by LoRaWAN protocol, so mainly handled by the node (the NS may also be involved). Gateway just forwards packets.
- Yes, SX1303 is also supported by ESXP1302.

dennis4lora, 2024-06-17:
I propose that I just work on sending the original JSON message to MQTT broker as the default behavior, then you can customize this to suit your specific requirements, which should be very easy: you can add callback or do changes in the thread directly.

If your Ethernet connects to a Router which provides DHCP service, then the wireless interface is not necessary and the logic would be simpler. To provide option for both DHCP and fixed IP, then Wi-Fi is needed.

For your two questions:
- Duty cycle is handled by LoRaWAN protocol, so mainly handled by the node (the NS may also be involved). Gateway just forwards packets.
- Yes, ESXP1302 supports both SX1302 and SX1303.

michcfr, 2024-06-17:
> I propose that I just work on sending the original JSON message to MQTT broker as the default behavior, then you can customize this to suit your specific requirements, which should be very easy: you can add callback or do changes in the thread directly.

ok

> If your Ethernet connects to a Router which provides DHCP service, then the wireless interface is not necessary and the logic would be simpler. To provide option for both DHCP and fixed IP, then Wi-Fi is needed.

yes, these two use cases are needed.
will you use the ethernet esp-idf driver, as suggested by Daniel? https://github.com/espressif/esp-idf/tree/v5.2.2/examples/ethernet/basic

> For your two questions:
>
> * Duty cycle is handled by LoRaWAN protocol, so mainly handled by the node (the NS may also be involved). Gateway just forwards packets.

thank you for clarifications.

> * Yes, ESXP1302 supports both SX1302 and SX1303.

great!

dennis4lora, 2024-06-17:
> will you use the ethernet esp-idf driver, as suggested by Daniel? https://github.com/espressif/esp-idf/tree/v5.2.2/examples/ethernet/basic

Yes, I think that's the right option.

michcfr, 2024-07-18:
hello,
do you have any update about the adaptation?

dennis4lora, 2024-08-16:
@michcfr

Sorry for my so late response. 😢

About how to implement MQTT supporting, I have some different opinion now: The data needs not to choose either UDP way or MQTT way, but instead it can/should go both ways. MQTT should be an add-on to the original UDP way. This makes more sense and is more useful for reality cases.

And I also started work on it today and had the [first commit](https://github.com/lora-gateway/esxp1302/commit/b31b793d4a66abcd191e25edf67b5517969a660c). I have to hard code the MQTT server address and Topic, but at least the gateway can receive mqtt messages and display it now.

This commit is in branch `esp-idf-v5.x` since I plan to upgrade `esp-idf` soon, but I also want to release `v0.9` first before merge that branch.

I hope to improve mqtt function in the coming days (or weeks). Any questions, please don't hesitate to ask. 😄

michcfr, 2024-08-19:
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

Thank you Dennis, that's a great news :-)

I agree, UDP and MQTT are complementary.
Do you plan in the future to create a config file to store MQTT related paramters: server address, topic, login/pwd...? How will be "activated" the MQTT add-on for the UDP way (#define? config file?...)?

again thank you for your attention

dennis4lora, 2024-08-21:
Yes, I'd like to use `#define ENABLE_MQTT` to enable/disable the whole MQTT feature on the project. And need to provide a way to change mqtt related parameters on the web UI (which is a relative big work and won't be available soon).

I will work on it step by step. Here is the [2nd commit](https://github.com/lora-gateway/esxp1302/commit/903c44498ce9cb7afe408f379082be611ba20252) to send `status` and `rxpk` messages to MQTT server...

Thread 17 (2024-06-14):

upgrade to esp-idf v5.x branch

dennis4lora, 2024-06-14:
To upgrade to esp-idf v5.x branch, it's not difficult. However, there is a small change on the GCC side makes esxp1302 containing lots of lines needing to be fixed accordingly.

Per the migration guide: https://docs.espressif.com/projects/esp-idf/en/latest/esp32/migration-guides/release-5.x/5.0/gcc.html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

For example, we have two ways to display the value of `uint32_t value` as:
```diff
- printf("value = %u\n", value);
+ printf("value = %" PRIu32 "\n",  value);
```
or simply as:
```diff
- printf("value = %u\n", value);
+ printf("value = %lu\n",  value);
```
I'm not sure which is the better way to choose:
- the first way supports both esp-idf v4.x and v5.x branch.
- the second way is much simpler but only works on v5.x and fails for v4.x.

So: **which way do you prefer?** should we keep v4.x support? your comments are welcome.

BTW: If you are interested, this [link](https://github.com/espressif/esp-idf/issues/9511) talked a lot of this issue.

danielkucera, 2024-06-14:
I am already testing the updated version, this is my branch:
https://github.com/lora-gateway/esxp1302/compare/main...danielkucera:esxp1302:idf-update

Mine only ignores the warnings for format because of:
```
build_unflags = -Werror=all
```
which is the default for platformio. Is is the same for plain esp-idf?

But to your question - I don't see a particular reason to keep the old version supported.

dennis4lora, 2024-06-17:
> which is the default for platformio. Is is the same for plain esp-idf?

I'm afraid not. Someone suggested that this can be done by adding `component_compile_options(-Wno-error=format= -Wno-format)` to **CMakeLists.txt**, but I can't make it correct to pass the compile step.

Anyway, I would like to fix it instead of bypass it. And I agree with your opinion that supporting v4.x isn't useful. So I'll follow the 2nd way.

dennis4lora, 2024-06-17:
After changed some `%u` to `%lu` locally, I realized there are in fact two ways to do it (still takes `uint32_t` for example):

- %u --> %lu
- uint32_t --> unsigned int

`uint32_t` used to be interpreted as **unsigned int** and now becomes **unsigned long**, so very likely the size extends from 32-bit to 64-bit. It's no harm for the correctness, but I'm afraid it takes more space and not be used since 32-bit is already enough in the original intention.

So change `uint32_t` to **unsigned int** seems more reasonable.

@danielkucera: What's your opinion? Thanks.

danielkucera, 2024-06-17:
good find, this is the best option IMO

dennis4lora, 2024-06-17:
Great!!

And I'm sure:

```shell
 sed -i 's/uint32_t/unsigned int/g' *.c *.h
```
is much quicker than manually working on the 1st way.  :rofl:

dennis4lora, 2024-06-18:
I just checked the spec, and found that for both Xtensa (ESP32 based) and RISCV32 (ESP32C3 based), `int` takes 4 bytes, `long` also takes 4 bytes.

I also changed all `uint32_t` to `unsigned int` and compiled using PlatformIO, the produced firmware sizes match exactly before this change for both esp32 and esp32c3.

So there is no harm (but also no gain) for this change, but it's easy and needed for esp-idf v5.x branch, so let's do it this way.

danielkucera, 2024-06-18:
Perfect.

dennis4lora, 2024-06-27:
The updates has been done in branch [esp-idf-v5.x](https://github.com/lora-gateway/esxp1302/tree/esp-idf-v5.x).

I've tested the build with `esp-idf v5.2`, and `espressif32@6.7.0`, both OK, but the produced size is more than 10% bigger.   :frowning_face:

danielkucera, 2025-06-11:
Hi @dennis4lora ,

how is this going? I think the increase is something we cannot avoid, esp-idf is getting more mature and there are many bug fixes so logically also the code base is growing.

Moreover, the v4 doesn't compile in platformio anymore: https://github.com/platformio/platform-espressif32/pull/1578

Can we push this somehow?

dennis4lora, 2025-06-13:
Yes. I planned long ago to release a new version based on current main branch, then merge all other branches together for future development (mqtt, 4G/Ethernet etc.). I just postponed this a little too long...

I'll handle this in the coming days. Thanks for pushing me. :-)

dennis4lora, 2025-06-24:
Thanks. I have just released `v0.9.0` (the esp32c3 binary firmware hasn't been tested yet).
I also merged/updated other branches. 😃

Since esp-idf v5.4.1 has been released a few months ago, I would like to update to that branch instead of the original planned v5.2 branch.
And how about the PlatformIO support? Should we also upgrade it to the latest version? Thanks.

danielkucera, 2025-06-24:
Yes, I think we should go to the latest PIO which is 6.11.0

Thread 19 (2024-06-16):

Make networking independent from app

danielkucera, 2024-06-16:
Hello,
I'd like to make networking independent from the packet forwarder app.
I see it happen in following steps:
- #18
- move network configuration handling to a separate file: wip: https://github.com/lora-gateway/esxp1302/compare/main...danielkucera:esxp1302:networking
- create a separate thread for network state changes handling
- add additional network connections (using e.g. esp internal mac for ethernet, GPRS with SIM800 via uart, usb-cdc, ...)

The sockets for packet forwarder can be created even without working connection (as with the webserver). The only relevant parts are DNS resolving during connection (solved in wip) and sending status/uplink packets - this has to be tested how it behaves during missing connection (if it drops after start and resolving server) but IMO it should be fine - we should just ignore a potential error during UDP packet send. Once the connection reestablishes it should continue sending.

What do you think about this?

dennis4lora, 2024-06-17:
@danielkucera

Thanks for this proposal, it paves the way to support multi types of network interface.

In fact, there is a problem in the original sx1302_hal: after `pkt-fwd` runs, if you disconnect the Ethernet cable then connect it again, `pkt-fwd` keeps run, but the packets won't be sent out to NS any more (I guess this is caused by how the sockets are created or configured but I didn't investigate).

I think esxp1302 `pkt-fwd` doesn't have this problem because: if Wi-Fi fails for a few seconds then re-connected, there is no logic to restart the `pkt-fwd` (I guess I tested this situation).

Of course, it needs careful thinking about the network state changes and some tests to make sure no mistake, but I think this idea is doable. :smile:

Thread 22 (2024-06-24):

improve web UI

dennis4lora, 2024-06-24:
Currently the web UI design is a little too inflexible and ugly.

There are a few reasons to make the improvement necessary:
- More items could be added in the future (such as option for NTP server; switch for LoRaWAN NS or MQTT server etc.)
- It could be accessed from either PC or cellphone.
- Does it make sense to add some basic help information?

So changing it to be more flexible (and a little pretty) would be useful. On the other hand, this function is not used so much, so it shouldn't cost too much  (flash and RAM) in order to be perfect.

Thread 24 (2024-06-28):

Connecting to TTN

StevenCellist, 2024-06-28:
Hi folks, I just got my concentrator card in the mail as well as the miniPCIe break-out a few days earlier (perfect & fast shipping!). If I understand correctly however, it is not possible yet to connect the ESXP1302 to TTN or other 'online' (non-local) network servers. Is that right, and if so, where should I look to try and see if I can get it running? Cheers!

danielkucera, 2024-06-29:
Hi, of course it is.
You just need to set you NS accordingly.
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

StevenCellist, 2024-06-29:
Ah, according to the [user guide](https://github.com/lora-gateway/esxp1302/blob/main/doc/user_guide.md#configuration-by-web-ui), it says that domain names don't work and IP addresses should be used.
And as far as I'm used to, I thought I'd need to set the API key for the gateway to function correctly.. how does that work here?

danielkucera, 2024-06-29:
That might be some old information, right @dennis4lora ?
Api key is only needed for the new protocol. Legacy packet forwarder works without. I don't remember exactly now if something had to be set in TTN console but I think no.

StevenCellist, 2024-06-29:
Do you have your ESXP connected to TTN? It sounds impossible to me that you can have it working without API key, because any and all packet forwarder gateways I've used including legacy ones require the API key.

danielkucera, 2024-06-29:
Yes, I do.

StevenCellist, 2024-06-29:
Apparently, the statistics on their own do not trigger TTN to show the gateway. Having resolved the I2C wiring means messages now come through and the gateway functions nicely. Definitely interesting there's no key required, but that's probably why it's called legacy ;)
Thank you!

danielkucera, 2024-06-29:
Nice, YW.

chunis, 2024-06-29:
> Ah, according to the [user guide](https://github.com/lora-gateway/esxp1302/blob/main/doc/user_guide.md#configuration-by-web-ui), it says that domain names don't work and IP addresses should be used.

That information is outdated now and needs to be corrected. Thanks for point it out. :-)

@danielkucera, @StevenCellist :

In fact, there are two kinds of gateway protocol both supported by Semtech:
- UDP based packet-forwarder (https://github.com/lora-net/sx1302_hal) (let's call it PF).
- Basics Station (https://github.com/lorabasics/basicstation) (let's call it BS).

The reason why there are 2 instead of 1, is because BS is designed by another company named TrackNet before it was acquired by Semtech. PF is older and simpler while BS has some advanced features but more complex. For example, it requires API key for `CUPS` (https://www.thethingsindustries.com/docs/gateways/concepts/lora-basics-station/cups/).

TTN provides some information for both:
- https://www.thethingsindustries.com/docs/gateways/concepts/udp/
- https://www.thethingsindustries.com/docs/gateways/concepts/lora-basics-station/

Final word: **ESXP1302 derives from PF**. That's why it doesn't require API key.

Closed 2024-06-29.

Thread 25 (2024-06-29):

ESXP1302 crashes as soon as uplink is received

StevenCellist, 2024-06-29:
I flashed my ESP32-S3 (don't have a C3 on hand) with the esp-idf v5.x branch but identical happens for v4.x.
There are multiple problems, but one of them is this: as soon as an uplink is received, the device crashes and reboots.
Only modification made is that I increased the available stack size for pkt_fwd by 4x because it crashed with the normal 4096 which did _not_ occur on v4.x

```
10:35:09.509 > ESP-ROM:esp32s3-20210327
10:35:09.514 > Build:Mar 27 2021
10:35:09.516 > rst:0x1 (POWERON),boot:0x29 (SPI_FAST_FLASH_BOOT)
10:35:09.521 > SPIWP:0xee
10:35:09.522 > mode:DIO, clock div:1
10:35:09.524 > load:0x3fce3810,len:0x178c
10:35:09.526 > load:0x403c9700,len:0x4
10:35:09.528 > load:0x403c9704,len:0xcbc
10:35:09.531 > load:0x403cc700,len:0x2da0
10:35:09.533 > entry 0x403c990c
10:35:09.535 > I (27) boot: ESP-IDF 5.2.1 2nd stage bootloader
10:35:09.540 > I (27) boot: compile time Jun 29 2024 10:21:28
10:35:09.546 > I (27) boot: Multicore bootloader
10:35:09.550 > I (30) boot: chip revision: v0.1
10:35:09.553 > I (34) boot.esp32s3: Boot SPI Speed : 80MHz
10:35:09.558 > I (38) boot.esp32s3: SPI Mode       : DIO
10:35:09.563 > I (43) boot.esp32s3: SPI Flash Size : 8MB
10:35:09.568 > I (48) boot: Enabling RNG early entropy source...
10:35:09.573 > I (53) boot: Partition Table:
10:35:09.577 > I (57) boot: ## Label            Usage          Type ST Offset   Length
10:35:09.584 > I (64) boot:  0 nvs              WiFi data        01 02 00009000 00006000
10:35:09.591 > I (72) boot:  1 phy_init         RF data          01 01 0000f000 00001000
10:35:09.599 > I (79) boot:  2 factory          factory app      00 00 00010000 00177000
10:35:09.606 > I (87) boot: End of partition table
10:35:09.611 > I (91) esp_image: segment 0: paddr=00010020 vaddr=3c0c0020 size=46d28h (290088) map
10:35:09.659 > I (151) esp_image: segment 1: paddr=00056d50 vaddr=3fc9bd00 size=05f7ch ( 24444) load
10:35:09.668 > I (157) esp_image: segment 2: paddr=0005ccd4 vaddr=40374000 size=03344h ( 13124) load
10:35:09.677 > I (160) esp_image: segment 3: paddr=00060020 vaddr=42000020 size=b3198h (733592) map
10:35:09.805 > I (297) esp_image: segment 4: paddr=001131c0 vaddr=40377344 size=148fch ( 84220) load
10:35:09.834 > I (326) boot: Loaded app from partition at offset 0x10000
10:35:09.840 > I (326) boot: Disabling RNG early entropy source...
10:35:09.846 > I (337) cpu_start: Multicore app
10:35:09.855 > I (347) cpu_start: Pro cpu start user code
10:35:09.861 > I (347) cpu_start: cpu freq: 160000000 Hz
10:35:09.865 > I (347) cpu_start: Application information:
10:35:09.870 > I (350) cpu_start: Project name:     ESXP1302-Pkt-Fwd
10:35:09.876 > I (356) cpu_start: App version:      v0.8.0-67-g2ac1132-dirty
10:35:09.882 > I (362) cpu_start: Compile time:     Jun 29 2024 10:20:52
10:35:09.888 > I (368) cpu_start: ELF file SHA256:  e810022f8485d5e9...
10:35:09.894 > I (374) cpu_start: ESP-IDF:          5.2.1
10:35:09.899 > I (379) cpu_start: Min chip rev:     v0.0
10:35:09.903 > I (384) cpu_start: Max chip rev:     v0.99
10:35:09.909 > I (389) cpu_start: Chip rev:         v0.1
10:35:09.913 > I (394) heap_init: Initializing. RAM available for dynamic allocation:
10:35:09.921 > I (401) heap_init: At 3FCB8410 len 00031300 (196 KiB): RAM
10:35:09.927 > I (407) heap_init: At 3FCE9710 len 00005724 (21 KiB): RAM
10:35:09.933 > I (413) heap_init: At 3FCF0000 len 00008000 (32 KiB): DRAM
10:35:09.939 > I (419) heap_init: At 600FE010 len 00001FD8 (7 KiB): RTCRAM
10:35:09.945 > I (426) spi_flash: detected chip: gd
10:35:09.949 > I (430) spi_flash: flash io: dio
10:35:09.952 > W (434) i2c: This driver is an old driver, please migrate your application code to adapt `driver/i2c_master.h`
10:35:09.964 > I (444) sleep: Configure to isolate all GPIO pins in sleep state
10:35:09.971 > I (451) sleep: Enable automatic switching of GPIO sleep configuration
10:35:09.977 > I (459) main_task: Started on CPU0
10:35:09.982 > I (469) main_task: Calling app_main()
10:35:09.986 >
10:35:09.986 >
10:35:09.987 > *** ESXP1302 Gateway. Version: 0.8.0 ***
10:35:09.990 >
10:35:09.990 >
10:35:10.758 > wifi_ssid: God is liefde @ 0x3fcbe6c4
10:35:10.762 > ns_host: eu1.cloud.thethings.network @ 0x3fcbe6d8
10:35:10.766 > ns_port: 1700 @ 0x3fcbe6f8
10:35:10.769 > gw_id: ce77157000000001 @ 0x3fcbe708
10:35:10.772 > wifi_mode: station @ 0x3fcbe720
10:35:10.775 > freq_region: eu868 @ 0x3fcbe730
10:35:10.778 > freq_radio0: 868100000 @ 0x3fcbe740
10:35:10.781 > freq_radio1: 868300000 @ 0x3fcbe750
10:35:10.784 > ntp_server: cn.pool.ntp.org @ 0x3fcbe760
10:35:11.148 > config wifi_mode = soft_ap
10:35:11.151 > set wifi_ssid: Done
10:35:11.152 > set wifi_pswd: Done
10:35:11.156 > set ns_host: Done
10:35:11.156 > set ns_port: Done
10:35:11.158 > set gw_id: Done
10:35:11.159 > set wifi_mode: Done
10:35:11.161 > set freq_region: Done
10:35:11.163 > set freq_radio0: Done
10:35:11.165 > set freq_radio1: Done
10:35:11.167 > set ntp_server: Done
10:35:11.169 > Save config to NVS... Done
10:35:11.172 > I (1649) gateway boot: ESP_WIFI_MODE_STA
10:35:11.176 > I (1659) pp: pp rom version: e7ae62f
10:35:11.180 > I (1659) net80211: net80211 rom version: e7ae62f
10:35:11.186 > I (1679) wifi:wifi driver task: 3fcc33b8, prio:23, stack:6656, core=0
10:35:11.203 > I (1699) wifi:wifi firmware version: a9f5b59
10:35:11.207 > I (1699) wifi:wifi certification version: v7.0
10:35:11.211 > I (1699) wifi:config NVS flash: enabled
10:35:11.215 > I (1699) wifi:config nano formating: disabled
10:35:11.219 > I (1699) wifi:Init data frame dynamic rx buffer num: 32
10:35:11.224 > I (1709) wifi:Init static rx mgmt buffer num: 5
10:35:11.228 > I (1709) wifi:Init management short buffer num: 32
10:35:11.233 > I (1709) wifi:Init dynamic tx buffer num: 32
10:35:11.237 > I (1719) wifi:Init static tx FG buffer num: 2
10:35:11.241 > I (1719) wifi:Init static rx buffer size: 1600
10:35:11.245 > I (1729) wifi:Init static rx buffer num: 10
10:35:11.249 > I (1729) wifi:Init dynamic rx buffer num: 32
10:35:11.253 > I (1739) wifi_init: rx ba win: 6
10:35:11.257 > I (1739) wifi_init: tcpip mbox: 32
10:35:11.261 > I (1739) wifi_init: udp mbox: 6
10:35:11.265 > I (1749) wifi_init: tcp mbox: 6
10:35:11.269 > I (1749) wifi_init: tcp tx win: 5744
10:35:11.272 > I (1749) wifi_init: tcp rx win: 5744
10:35:11.277 > I (1759) wifi_init: tcp mss: 1440
10:35:11.281 > I (1759) wifi_init: WiFi IRAM OP enabled
10:35:11.286 > I (1769) wifi_init: WiFi RX IRAM OP enabled
10:35:11.291 > I (1779) phy_init: phy_version 640,cd64a1a,Jan 24 2024,17:28:12
10:35:11.324 > I (1819) wifi:mode : sta (f4:12:fa:67:14:b0)
10:35:11.328 > I (1819) wifi:enable tsf
10:35:11.330 > I (1819) wifi station: wifi_init_sta finished.
10:35:11.336 > I (1819) esp32 web server: Starting web server on port: '80'
10:35:11.342 > I (1829) wifi:new:<6,0>, old:<1,0>, ap:<255,255>, sta:<6,0>, prof:1
10:35:11.347 > I (1829) wifi:state: init -> auth (b0)
10:35:11.352 > I (1829) esp32 web server: Registering URI handlers
10:35:11.357 >
10:35:11.357 >
10:35:11.357 >  ---- pkt_fwd ----
10:35:11.359 > I (1839) wifi:state: auth -> assoc (0)
10:35:11.363 >
10:35:11.363 > Available options:
10:35:11.365 >  -h                   print this help
10:35:11.368 > I (1849) wifi:state: assoc -> run (10)
10:35:11.371 >  -u <wifi ssid>       Wifi SSID
10:35:11.374 >  -p <wifi password>   Wifi Password
10:35:11.377 >  --host <NS Host>     NS Host
10:35:11.380 >  --port <NS Port>     NS Port
10:35:11.383 >  --gwid <gateway id>  Gateway ID
10:35:11.388 > I (1879) wifi:connected with God is liefde, aid = 5, channel 6, BW20, bssid = f0:9f:c2:f4:1f:8b
10:35:11.398 > I (1879) wifi:security: WPA2-PSK, phy: bgn, rssi: -71
10:35:11.402 > I (1889) wifi:pm start, type: 1
10:35:11.405 >
10:35:11.406 > I (1889) wifi:dp: 1, bi: 102400, li: 3, scale listen interval from 307200 us to 307200 us
10:35:11.413 > I (1899) wifi:set rx beacon pti, rx_bcn_pti: 0, bcn_timeout: 25000, mt_pti: 0, mt_time: 10000
10:35:11.421 > I (1899) wifi:AP's beacon interval = 102400 us, DTIM period = 1
10:35:11.427 > I (1919) wifi:<ba-add>idx:0 (ifx:0, f0:9f:c2:f4:1f:8b), tid:0, ssn:0, winSize:64
10:35:11.462 >
10:35:11.463 > Type 'help' to get the list of commands.
10:35:11.466 > Use UP/DOWN arrows to navigate through command history.
10:35:11.472 > Press TAB when typing command name to auto-complete.
10:35:11.476 > I (1959) main_task: Returned from app_main()
10:35:11.482 > ESXP1302_GW> I (2909) esp_netif_handlers: sta ip: 192.168.1.31, mask: 255.255.255.0, gw: 192.168.1.1
10:35:12.424 > I (2909) wifi station: connected to ap (SSID:God is liefde) succeeded
10:35:12.430 > I (2919) wifi station: got ip:192.168.1.31
10:35:12.799 > Wi-Fi ready. Start tasks...
10:35:12.802 > config wifi_mode = station
10:35:12.804 > set wifi_ssid: Done
10:35:12.806 > set wifi_pswd: Done
10:35:12.808 > set ns_host: Done
10:35:12.810 > set ns_port: Done
10:35:12.811 > set gw_id: Done
10:35:12.814 > set wifi_mode: Done
10:35:12.815 > set freq_region: Done
10:35:12.817 > set freq_radio0: Done
10:35:12.819 > set freq_radio1: Done
10:35:12.821 > set ntp_server: Done
10:35:12.823 > Save config to NVS... Done
10:35:12.826 > *** Packet Forwarder ***
10:35:12.828 > Version: undefined
10:35:12.830 > *** SX1302 HAL library version info ***
10:35:12.833 > Version: 2.1.0;
10:35:12.834 > ***
10:35:12.834 > INFO: Little endian host
10:35:12.837 > Config loaded into memory
10:35:12.843 > INFO: conf array does contain a JSON object named SX130x_conf, parsing SX1302 parameters
10:35:12.851 > INFO: com_type SPI, com_path /dev/spidev0.0, lorawan_public 1, clksrc 0, full_duplex 0
10:35:12.859 > INFO: antenna_gain 0 dBi
10:35:12.861 > INFO: conf array does not contain a JSON object for fine timestamp
10:35:12.867 > INFO: no configuration for SX1261
10:35:12.870 > INFO: Configuring Tx Gain LUT for rf_chain 0 with 16 indexes for sx1250
10:35:12.876 > INFO: radio 0 enabled (type SX1250), center frequency 868100000, RSSI offset -215.399994, tx enabled 1, single input mode 0
10:35:12.887 > INFO: radio 1 enabled (type SX1250), center frequency 868300000, RSSI offset -215.399994, tx enabled 0, single input mode 0
10:35:12.898 > INFO: no configuration for LoRa multi-SF spreading factors enabling
10:35:12.904 > INFO: Lora multi-SF channel 0>  radio 1, IF -400000 Hz, 125 kHz bw, SF 5 to 12
10:35:12.910 > INFO: Lora multi-SF channel 1>  radio 1, IF -200000 Hz, 125 kHz bw, SF 5 to 12
10:35:12.918 > INFO: Lora multi-SF channel 2>  radio 1, IF 0 Hz, 125 kHz bw, SF 5 to 12
10:35:12.924 > INFO: Lora multi-SF channel 3>  radio 0, IF -400000 Hz, 125 kHz bw, SF 5 to 12
10:35:12.931 > INFO: Lora multi-SF channel 4>  radio 0, IF -200000 Hz, 125 kHz bw, SF 5 to 12
10:35:12.938 > INFO: Lora multi-SF channel 5>  radio 0, IF 0 Hz, 125 kHz bw, SF 5 to 12
10:35:12.944 > INFO: Lora multi-SF channel 6>  radio 0, IF 200000 Hz, 125 kHz bw, SF 5 to 12
10:35:12.951 > INFO: Lora multi-SF channel 7>  radio 0, IF 400000 Hz, 125 kHz bw, SF 5 to 12
10:35:12.958 > INFO: Lora std channel> radio 1, IF -200000 Hz, 250000 Hz bw, SF 7, Explicit header
10:35:12.966 > INFO: FSK channel> radio 1, IF 300000 Hz, 125000 Hz bw, 50000 bps datarate
10:35:12.975 > INFO: conf array does contain a JSON object named gateway_conf, parsing gateway parameters
10:35:12.984 > INFO: gateway MAC address is configured to AA555A0000000000
10:35:12.989 > INFO: server hostname or IP address is configured to "localhost"
10:35:12.995 > INFO: upstream port is configured to "1730"
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
danielkucera, 2024-06-29:
Do you have I2C connected correctly? What kind of concentrator are you using?

StevenCellist, 2024-06-29:
Interesting, thank you, didn't know I2C was crucially important for the device to function. All good now!

StevenCellist, 2024-06-29:
For completeness BTW: LR1302

danielkucera, 2024-06-29:
You can disable it in the code but when it is enabled it should compute some temp corrections regarding signal strength or so...

Closed 2024-06-29.

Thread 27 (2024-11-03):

Adaptation the GW to SX1301 chip

Zupayruna1, 2024-11-03:
Hello everyone, excellent work with this project! I'd like to know about how to change the code for the SX1301 Lora GW Chip? I've a gateway but with the sx1301 (heltec lora gw HTM01 868Mhz).

Best regards,
Andrés

dennis4lora, 2024-11-06:
I guess your gateway is [this one](https://docs.heltec.cn/en/gateway/ht-m01/quick_start.html)?

This "PicoCell gateway" bases on Raspberry Pi or Windows, and the LoRa chip is SX1308 (similar as SX1301). And the related projects are these three:
- https://github.com/Lora-net/picoGW_hal
- https://github.com/Lora-net/picoGW_packet_forwarder
- https://github.com/Lora-net/picoGW_mcu

ESXP1302 bases on ESP32 platform using SPI. I guess PicoCell gateway also can use SPI as the communication interface.

So do you want to switch to ESP32? Even so, I'm afraid the HAL for SX1301 and SX1302 are different, so the porting though doable but won't be easy. You may try it and I can give some guidance, but I have not plan to make ESXP1302 supporting SX1301...

Zupayruna1, 2024-11-27:
Hi, yes I would like to provide support for SX1301 in your project, if you can give me some guidance for that I would really appreciate it!

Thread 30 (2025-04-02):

gateway programs cannot connect to the ns server when Ethernet and pppos

keeshow, 2025-04-02:
when I use WIFI, gateway programs can interact with the server; But when I use Ethernet or pppos, gateway programs can start normally and the log output is sending information, but I can't get any messages from the ns server, so I guess the gateway is not connected to the server(Ethernet or pppos are networked because I can ping the server )

keeshow, 2025-04-02:
> Hi [@keeshow](https://github.com/keeshow) , I don't think this project supports ethernet or ppoe currently. What hardware are you using?

The mcu I use is esp32, what do you mean by not supporting Ethernet and pppos? If my esp32 can access the Internet, theoretically the gateway program should also be able to connect to the ns server, does this gateway only connect to the server for wifi?

dennis4lora, 2025-04-03:
ESP32 supports Wi-Fi and Bluetooth without any external components needed, but surely you can't connect a wired cable to ESP32 directly. So, how do you enable Ethernet support?
Now this project only uses Wi-Fi for connection; unfortunately, automatically choose between Wi-Fi / Ethernet / 4G is doable but available yet... :-(

keeshow, 2025-04-17:
I have currently achieved Internet access via wifi, Ethernet and 4g on the esp32. However, among these three Internet access methods, the packet_forwarder program can only operate normally in the wifi situation, but not in the other two. May I ask where the esxp1302 is restricted and can only operate normally under Wi-Fi conditions?
Another issue is that I removed all the Internet connection content from the esxp1302 and implemented three Internet access methods by myself. Under these three Internet access methods, if the current Internet access method is Ethernet or 4g, the esxp1302 will cause the device to lose the network after starting the gateway program (but this will not happen under WiFi conditions).

dennis4lora, 2025-04-18:
> May I ask where the esxp1302 is restricted and can only operate normally under Wi-Fi conditions?

Currently esxp1302 only uses Wi-Fi as backhaul, so it needs Wi-Fi be ready to start pkt-fwd, and pkt-fwd is also controlled by Wi-Fi state. This logic locates in the code `main/packet_forwarder/lora_pkt_fwd.c` in function `app_main()` as below:
```c
    if(soft_ap_mode == true){
        ...
    } else {
        ...
    }
```

However, for Ethernet, it's much simpler since we assume the connection is always available, and above logic is not needed.

So you can try this as a quick and dirty way to skip it and start pkt-fwd directly: comment above code and instead just call `xTaskCreatePinnedToCore(((TaskFunction_t) pkt_fwd_task), "pkt_fwd", 1*4096, NULL, 6, &pkt_fwd_handle, 0);`.

keeshow, 2025-04-18:
Yes, I have removed the network-related functions in esxp1302 and implemented the network connection separately (which has been verified to be okay). Meanwhile, I also re-encapsulated the startup of pkt_fwd as follows:
`
void start_lora_gateway(void)
{
    if (task_started == false)
    {
        ESP_LOGI(BOOT_TAG, "Starting LoRaWAN gateway...");

        sntp_setoperatingmode(SNTP_OPMODE_POLL);
        if (config[NTP_SERVER].val != NULL)
        {
            sntp_setservername(0, config[NTP_SERVER].val);
        }
        else
        {
            sntp_setservername(0, NTP_SERVER_ADDR);
        }
        sntp_init();

        if (xTaskCreatePinnedToCore(((TaskFunction_t)pkt_fwd_task), "pkt_fwd", 1 * 4096, NULL, 6, &pkt_fwd_handle, 0) == pdPASS)
        {
            task_started = true;
            ESP_LOGI(BOOT_TAG, "LoRaWAN gateway task created successfully");
        }
        else
        {
            ESP_LOGE(BOOT_TAG, "Failed to create LoRaWAN gateway task");
        }
    }
    else
    {
        ESP_LOGE(BOOT_TAG, "LoRaWAN gateway task already started");
    }
}
`
And I adapted this start_lora_gateway function to my own main function, as follows:
`
void app_main(void)
{
    ESP_ERROR_CHECK(nvs_flash_init());

    ESP_ERROR_CHECK(esp_netif_init());

    ESP_ERROR_CHECK(esp_event_loop_create_default());

    net_manager_init_all();

    esxp1302_init(); // Call here

    while (1)
    {
        network_test();

        vTaskDelay(pdMS_TO_TICKS(10000));
    }
}
`
The current situation is that the esxp1302 program can only work normally when connected to a WiFi network. If it is in an Ethernet or 4g network connection state, once the esxp1302 program is started, it will cause the network to be unusable.I think it's really amazing. I once wondered if the esxp1302 was limited to being compatible only with WiFi somewhere.

Based on my above description, can you figure out what caused this? Thank you very much for your help.

danielkucera, 2025-04-18:
I tried to separate the network before and it was working (see #19 ) but I only tested with wifi.
Can you share your changes as a branch? Are you getting some specific errors?

StevenCellist, 2025-05-07:
@keeshow any chance you can share your work? I'd be interested to have a look at it.

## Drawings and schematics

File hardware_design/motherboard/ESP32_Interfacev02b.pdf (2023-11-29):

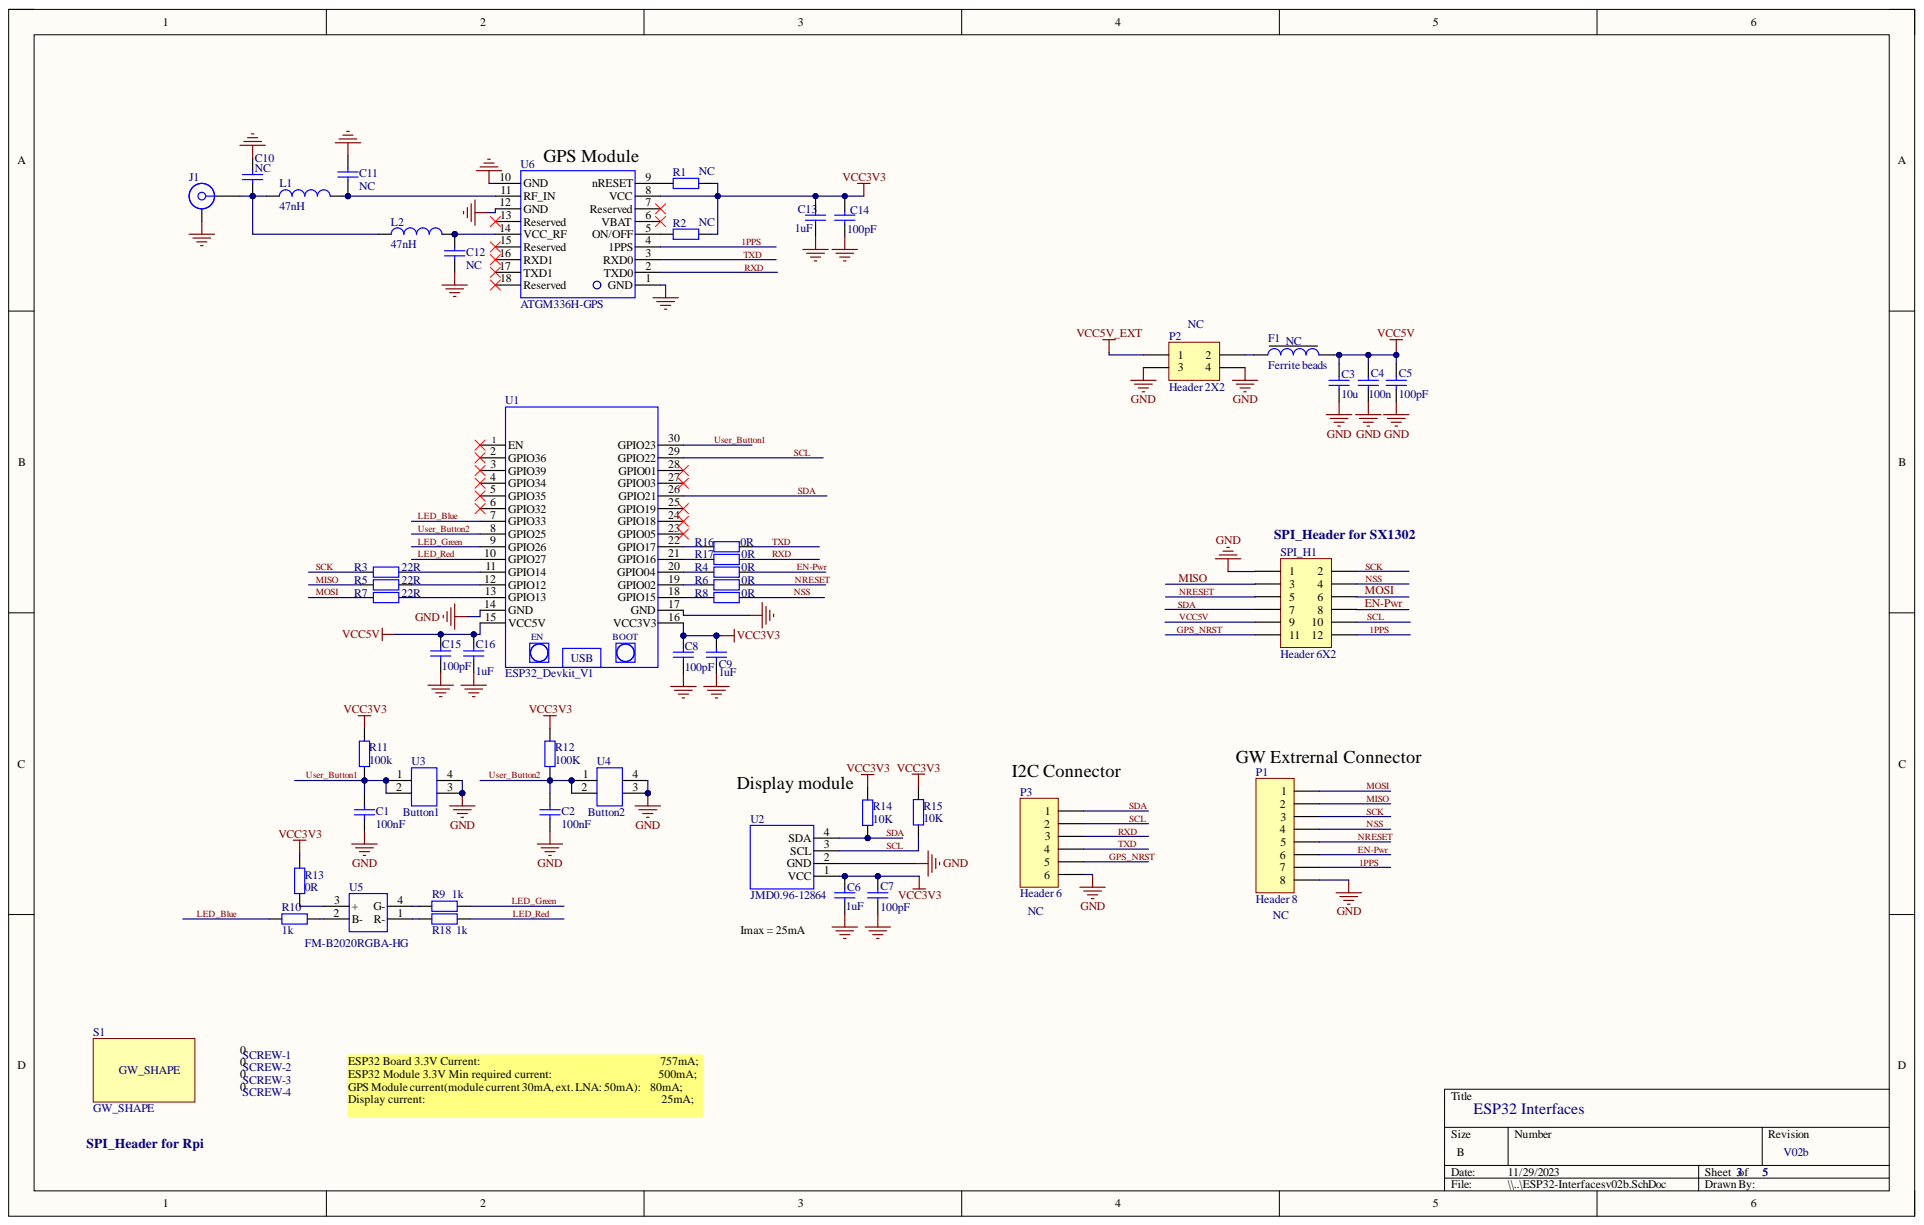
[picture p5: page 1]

NC VCC5V_EXT VCC5V P2

GPS Module current(module current 30mA, ext. LNA: 50mA): 80mA;

Size B | Number | Revision V02b

Date: 11/29/2023 | Sheet of 3 3 5 5
File: \\..\ESP32-Interfacesv02b.SchDoc | Drawn By:

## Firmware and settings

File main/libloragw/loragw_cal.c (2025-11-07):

/*
 / _____)             _              | |
( (____  _____ ____ _| |_ _____  ____| |__
 \____ \| ___ |    (_   _) ___ |/ ___)  _ \
 _____) ) ____| | | || |_| ____( (___| | | |
(______/|_____)_|_|_| \__)_____)\____)_| |_|
  (C)2019 Semtech

Description:
    LoRa concentrator radio calibration functions

License: Revised BSD License, see LICENSE.TXT file include in the project
*/


/* -------------------------------------------------------------------------- */
/* --- DEPENDANCIES --------------------------------------------------------- */

#include <stdint.h>     /* C99 types */
#include <stdio.h>      /* printf fprintf */
#include <math.h>       /* log10 */

#include "loragw_reg.h"
#include "loragw_aux.h"
#include "loragw_hal.h"
#include "loragw_sx1302.h"
#include "loragw_sx125x.h"
#include "loragw_cal.h"

/* -------------------------------------------------------------------------- */
/* --- DEBUG FLAGS ---------------------------------------------------------- */

#define TX_CALIB_DONE_BY_HAL    0

/* -------------------------------------------------------------------------- */
/* --- PRIVATE MACROS ------------------------------------------------------- */

#define ARRAY_SIZE(a) (sizeof(a) / sizeof((a)[0]))
#if DEBUG_CAL == 1
    #define DEBUG_MSG(str)                fprintf(stdout, str)
    #define DEBUG_PRINTF(fmt, args...)    fprintf(stdout,"%s:%d: "fmt, __FUNCTION__, __LINE__, args)
    #define CHECK_NULL(a)                if(a==NULL){fprintf(stderr,"%s:%d: ERROR: NULL POINTER AS ARGUMENT\n", __FUNCTION__, __LINE__);return LGW_SPI_ERROR;}
#else
    #define DEBUG_MSG(str)
    #define DEBUG_PRINTF(fmt, args...)
    #define CHECK_NULL(a)                if(a==NULL){return LGW_SPI_ERROR;}
#endif

/* -------------------------------------------------------------------------- */
/* --- PRIVATE CONSTANTS ---------------------------------------------------- */

#define CAL_TX_TONE_FREQ_HZ     250000
#define CAL_ITER                3 /* Number of calibration iterations */
#define CAL_TX_CORR_DURATION    0 /* 0:1ms, 1:2ms, 2:4ms, 3:8ms */

/* -------------------------------------------------------------------------- */
/* --- PRIVATE VARIABLES -------------------------------------------- */

/* Record Rx IQ mismatch corrections from calibration */
static int8_t rf_rx_image_amp[LGW_RF_CHAIN_NB] = {0, 0};
static int8_t rf_rx_image_phi[LGW_RF_CHAIN_NB] = {0, 0};

/* -------------------------------------------------------------------------- */
/* --- PRIVATE FUNCTIONS DEFINITION ----------------------------------------- */

void cal_rx_result_init(struct lgw_sx125x_cal_rx_result_s *res_rx_min, struct lgw_sx125x_cal_rx_result_s *res_rx_max);
void cal_rx_result_sort(struct lgw_sx125x_cal_rx_result_s *res_rx, struct lgw_sx125x_cal_rx_result_s *res_rx_min, struct lgw_sx125x_cal_rx_result_s *res_rx_max);
bool cal_rx_result_assert(struct lgw_sx125x_cal_rx_result_s *res_rx_min, struct lgw_sx125x_cal_rx_result_s *res_rx_max);
int sx125x_cal_rx_image(uint8_t rf_chain, unsigned int freq_hz, bool use_loopback, uint8_t radio_type, struct lgw_sx125x_cal_rx_result_s * res);

void cal_tx_result_init(struct lgw_sx125x_cal_tx_result_s *res_tx_min, struct lgw_sx125x_cal_tx_result_s *res_tx_max);
void cal_tx_result_sort(struct lgw_sx125x_cal_tx_result_s *res_tx, struct lgw_sx125x_cal_tx_result_s *res_tx_min, struct lgw_sx125x_cal_tx_result_s *res_tx_max);
bool cal_tx_result_assert(struct lgw_sx125x_cal_tx_result_s *res_tx_min, struct lgw_sx125x_cal_tx_result_s *res_tx_max);
int sx125x_cal_tx_dc_offset(uint8_t rf_chain, unsigned int freq_hz, uint8_t dac_gain, uint8_t mix_gain, uint8_t radio_type, struct lgw_sx125x_cal_tx_result_s * res);

/* -------------------------------------------------------------------------- */
/* --- PUBLIC FUNCTIONS DEFINITION ------------------------------------------ */

int sx1302_cal_start(uint8_t version, struct lgw_conf_rxrf_s * rf_chain_cfg, struct lgw_tx_gain_lut_s * txgain_lut) {
    int i, j, k;
    uint8_t val;
    bool cal_status = false;
    uint8_t x_max;
    int x_max_idx;
    uint8_t dac_gain[LGW_RF_CHAIN_NB][TX_GAIN_LUT_SIZE_MAX];
    uint8_t mix_gain[LGW_RF_CHAIN_NB][TX_GAIN_LUT_SIZE_MAX];
    int8_t offset_i[LGW_RF_CHAIN_NB][TX_GAIN_LUT_SIZE_MAX];
    int8_t offset_q[LGW_RF_CHAIN_NB][TX_GAIN_LUT_SIZE_MAX];
    uint8_t nb_gains[LGW_RF_CHAIN_NB];
    bool unique_gains;
    struct lgw_sx125x_cal_rx_result_s cal_rx[CAL_ITER], cal_rx_min, cal_rx_max;
    struct lgw_sx125x_cal_tx_result_s cal_tx[CAL_ITER], cal_tx_min, cal_tx_max;

    /* Wait for AGC fw to be started, and VERSION available in mailbox */
    sx1302_agc_wait_status(0x01); /* fw has started, VERSION is ready in mailbox */

    sx1302_agc_mailbox_read(0, &val);
    if (val != version) {
        printf("ERROR: wrong CAL fw version (%d)\n", val);
        return LGW_HAL_ERROR;
    }
    printf("CAL FW VERSION: %d\n", val);

    /* notify CAL that it can resume */
    sx1302_agc_mailbox_write(3, 0xFF);

    /* Wait for AGC to acknoledge */
    sx1302_agc_wait_status(0x00);

    printf("CAL: started\n");

    /* Run Rx image calibration */
    for (i = 0; i < LGW_RF_CHAIN_NB; i++) {
        if (rf_chain_cfg[i].enable) {
            /* Calibration using the other radio for Tx */
            if (rf_chain_cfg[0].type == rf_chain_cfg[1].type) {
                cal_rx_result_init(&cal_rx_min, &cal_rx_max);
                for (j = 0; j < CAL_ITER; j++) {
                    sx125x_cal_rx_image(i, rf_chain_cfg[i].freq_hz, false, rf_chain_cfg[i].type, &cal_rx[j]);
                    cal_rx_result_sort(&cal_rx[j], &cal_rx_min, &cal_rx_max);
                }
                cal_status = cal_rx_result_assert(&cal_rx_min, &cal_rx_max);
            }

            /* If failed or different radios, run calibration using RF loopback (assuming that it is better than no calibration) */
            if ((cal_status == false) || (rf_chain_cfg[0].type != rf_chain_cfg[1].type)) {
                cal_rx_result_init(&cal_rx_min, &cal_rx_max);
                for (j = 0; j < CAL_ITER; j++) {
                    sx125x_cal_rx_image(i, rf_chain_cfg[i].freq_hz, true, rf_chain_cfg[i].type, &cal_rx[j]);
                    cal_rx_result_sort(&cal_rx[j], &cal_rx_min, &cal_rx_max);
                }
                cal_status = cal_rx_result_assert(&cal_rx_min, &cal_rx_max);
            }

            if (cal_status == false) {
                DEBUG_MSG("*********************************************\n");
                DEBUG_PRINTF("ERROR: Rx image calibration of radio %d failed\n",i);
                DEBUG_MSG("*********************************************\n");
                return LGW_HAL_ERROR;
            }
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

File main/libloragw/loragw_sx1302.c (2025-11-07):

/*
 / _____)             _              | |
( (____  _____ ____ _| |_ _____  ____| |__
 \____ \| ___ |    (_   _) ___ |/ ___)  _ \
 _____) ) ____| | | || |_| ____( (___| | | |
(______/|_____)_|_|_| \__)_____)\____)_| |_|
  (C)2019 Semtech

Description:
    SX1302 Hardware Abstraction Layer entry functions.

License: Revised BSD License, see LICENSE.TXT file include in the project
*/


/* -------------------------------------------------------------------------- */
/* --- DEPENDANCIES --------------------------------------------------------- */

#include <stdint.h>     /* C99 types */
#include <stdio.h>      /* printf fprintf */
#include <string.h>     /* memcmp */
#include <math.h>       /* pow, cell */
#include <inttypes.h>
#include <time.h>

#include "loragw_reg.h"
#include "loragw_aux.h"
#include "loragw_hal.h"
#include "loragw_sx1302.h"
#include "loragw_sx1302_timestamp.h"
#include "loragw_sx1302_rx.h"
#include "loragw_sx1250.h"
#include "loragw_agc_params.h"
#include "loragw_cal.h"
#include "loragw_debug.h"

/* -------------------------------------------------------------------------- */
/* --- PRIVATE MACROS ------------------------------------------------------- */

#define ARRAY_SIZE(a) (sizeof(a) / sizeof((a)[0]))
#if DEBUG_SX1302 == 1
    #define DEBUG_MSG(str)              fprintf(stdout, str)
    #define DEBUG_PRINTF(fmt, args...)  fprintf(stdout, fmt, args)
    #define CHECK_NULL(a)               if(a==NULL){fprintf(stderr,"%s:%d: ERROR: NULL POINTER AS ARGUMENT\n", __FUNCTION__, __LINE__);return LGW_REG_ERROR;}
#else
    #define DEBUG_MSG(str)
    #define DEBUG_PRINTF(fmt, args...)
    #define CHECK_NULL(a)               if(a==NULL){return LGW_REG_ERROR;}
#endif
#define CHECK_ERR(a)                    if(a==-1){return LGW_REG_ERROR;}

#define IF_HZ_TO_REG(f)     ((f * 32) / 15625)

#define SX1302_FREQ_TO_REG(f)   (unsigned int)((uint64_t)f * (1 << 18) / 32000000U)

/* -------------------------------------------------------------------------- */
/* --- PRIVATE TYPES -------------------------------------------------------- */

/* -------------------------------------------------------------------------- */
/* --- PRIVATE CONSTANTS ---------------------------------------------------- */

#define AGC_RADIO_A_INIT_DONE   0x80
#define AGC_RADIO_B_INIT_DONE   0x20

#define MCU_AGC                 0x01
#define MCU_ARB                 0x02

#define AGC_MEM_ADDR            0x0000
#define ARB_MEM_ADDR            0x2000

#define MCU_FW_SIZE             8192 /* size of the firmware IN BYTES (= twice the number of 14b words) */

#define FW_VERSION_CAL          1 /* Expected version of calibration firmware */

#define RSSI_FSK_POLY_0         90.636423 /* polynomiam coefficients to linearize FSK RSSI */
#define RSSI_FSK_POLY_1         0.420835
#define RSSI_FSK_POLY_2         0.007129
#define RSSI_FSK_POLY_3         -0.000026

#define FREQ_OFFSET_LSB_125KHZ  0.11920929f     /* 125000 * 32 / 2^6 / 2^19 */
#define FREQ_OFFSET_LSB_250KHZ  0.238418579f    /* 250000 * 32 / 2^6 / 2^19 */
#define FREQ_OFFSET_LSB_500KHZ  0.476837158f    /* 500000 * 32 / 2^6 / 2^19 */

/* sx1302 hardware modem capabilities */
#define LGW_IFMODEM_CONFIG {\
        IF_LORA_MULTI, \
        IF_LORA_MULTI, \
        IF_LORA_MULTI, \
        IF_LORA_MULTI, \
        IF_LORA_MULTI, \
        IF_LORA_MULTI, \
        IF_LORA_MULTI, \
        IF_LORA_MULTI, \
        IF_LORA_STD, \
        IF_FSK_STD } /* configuration of available IF chains and modems on the hardware */

/* constant arrays defining hardware capability */
const uint8_t ifmod_config[LGW_IF_CHAIN_NB] = LGW_IFMODEM_CONFIG;

#define MIN_LORA_PREAMBLE   6
#define STD_LORA_PREAMBLE   8
#define MIN_FSK_PREAMBLE    3
#define STD_FSK_PREAMBLE    5

#define GPIO_CFG_REGISTER               0x00
#define GPIO_CFG_AGC                    0x01
#define GPIO_CFG_ARB                    0x02
#define GPIO_CFG_SPI_EXP_1              0x03
#define GPIO_CFG_CSN_SPI_EXP            0x04
#define GPIO_CFG_SPI_EXP_2              0x05
#define GPIO_CFG_UART                   0x06
#define GPIO_CFG_SX1255_IQ              0x07
#define GPIO_CFG_SX1261_IQ              0x08
#define GPIO_CFG_STATUS                 0x09
#define GPIO_CFG_MBIST                  0x0A
#define GPIO_CFG_OTP                    0x0B

/* -------------------------------------------------------------------------- */
/* --- PRIVATE VARIABLES ---------------------------------------------------- */

/* Radio calibration firmware */
#include "cal_fw.var" /* text_cal_sx1257_16_Nov_1 */

/* Buffer to hold RX data */
rx_buffer_t rx_buffer;

/* Internal timestamp counter */
timestamp_counter_t counter_us;

/* -------------------------------------------------------------------------- */
/* --- PRIVATE FUNCTIONS DECLARATION ---------------------------------------- */

/**
@brief TODO
@param TODO
@return TODO
*/
extern int32_t lgw_sf_getval(int x);

/**
@brief TODO
@param TODO
@return TODO
*/
extern int32_t lgw_bw_getval(int x);

/**
@brief TODO
@param TODO
@return TODO
*/
void lora_crc16(const char data, int *crc);

/* -------------------------------------------------------------------------- */
/* --- INTERNAL SHARED VARIABLES -------------------------------------------- */

/* Log file */
extern FILE * log_file;
uint8_t fw_check[MCU_FW_SIZE];

/* -------------------------------------------------------------------------- */
/* --- PRIVATE FUNCTIONS DEFINITION ----------------------------------------- */

int calculate_freq_to_time_drift(unsigned int freq_hz, uint8_t bw, uint16_t * mant, uint8_t * exp) {
    uint64_t mantissa_u64;
    uint8_t exponent = 0;
    int32_t bw_hz;

    /* check input variables */
    CHECK_NULL(mant);
    CHECK_NULL(exp);

    bw_hz = lgw_bw_getval(bw);
    if (bw_hz < 0) {
        printf("ERROR: Unsupported bandwidth for frequency to time drift calculation\n");
        return LGW_REG_ERROR;
    }

    mantissa_u64 = (uint64_t)bw_hz * (2 << (20-1)) / freq_hz;
    while (mantissa_u64 < 2048) {
        exponent += 1;
        mantissa_u64 <<= 1;
    }

    *mant = (uint16_t)mantissa_u64;
    *exp = exponent;

    return LGW_REG_SUCCESS;
}

/* ~~~~~~~~~~~~~~~~~~~~~~~~~~~~~~~~ */
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

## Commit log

2020-04-29 SPI communication works
2020-05-20 disable SPI debug
2020-06-01 corrected wait_ms(), and spi works for sx1250 now
2020-06-02 add loragw_stts751.* for i2c function
2020-06-02 porting for i2c done; time for happily debug. :-)
2020-06-02 i2c works
2020-06-04 lots of changes to GPS code; won't compile since it needs loragw_hal.c which hasn't been imported/updated yet
    modifié : loragw_gps.c
    modifié : loragw_gps.h
    modifié : test/test_loragw_gps.c
    [loragw_gps.c, loragw_gps.h]
2020-06-10 remove spidev_path and i2cdev_path
2020-06-10 changes for GPS; but still have issue; postpone for future debug when GPS is used
    [loragw_cal.c, loragw_gps.c]
2020-06-18 add loragw_gpio.* for reset the gateway using GPIO Pins
    [loragw_gpio.c]
2020-06-19 simplify i2c functions
2020-06-19 move a 8K array out of function to avoid stack overflow
    [loragw_sx1302.c]
2020-06-19 simplify i2c in loragw_hal.c
2020-07-01 changes to avoid redefine _GNU_SOURCE, not sure '_GNU_SOURCE' is really needed or not
    [loragw_gps.h]
2020-10-28 thread_up() works. need to disable stackoverflow check
2021-11-30 packet-forwarder works, with LED support
2021-12-03 blink LEDs to last a specific time
2021-12-06 fix small issues in the OLED display driver
2021-12-06 display temperature
2021-12-13 led task need to be put ahead for the mutex to init
2021-12-17 control esp32 reboot from webpage works
2022-01-11 add timer for reboot
2022-01-20 use user button 1 and 2 to control which mode boot into: 1=soft_ap; 2=station
2022-01-28 show current configs in the web page
2022-02-16 add display about config wifi in case wifi never be configed
2023-11-29 add motherboard ref design
    [ESP32-Interfacesv02b.SchDoc, ESP32_Interfaces_Board_v02b1.PcbDoc, ESP32_Interfacev02b.PrjPCB]
2023-11-29 enable internal pullups on button pins
2023-12-05 allow working without temp sensor
2023-12-19 add design files for the case
    [esxp1302_bottom_case.FCStd, esxp1302_bottom_case.stl, esxp1302_top_case.FCStd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]
2023-12-26 Revert "move HAL code to main/libloragw", In order to keep the git history of libloragw files
    This reverts commit 0abed25e0f6ed06fdafbb013bd42a0447c5453a3.
    [loragw_cal.c, loragw_gpio.c]
2023-12-26 i2c: add function 'i2c_esp32_write_buf()' and other trivial corrections
    [loragw_i2c.c, loragw_i2c.h]
2023-12-26 simplify i2c_esp32_write()
2023-12-26 remove usb related code since esxp1302 doesn't support it
    [loragw_usb.c, sx1250_usb.c]
2023-12-26 update libloragw/loragw_ad5338r.* for esp32 platform
2024-01-05 Revert "remove usb related code since esxp1302 doesn't support it" to keep the interface
    This reverts commit e455b4fe20e1fa91fd9c97cfa15e59a6b34e7323.
    [loragw_usb.c, sx1250_usb.c]
2024-01-10 port libloragw/loragw_reg.*; no test so could be buggy
    [loragw_reg.h]
2024-01-10 add support for esp32c3
2024-02-07 re-structure libtools and switch to use libloragw
2024-02-21 fixes to make spi (read) works
    [loragw_com.c, loragw_spi.c, sx1261_com.c]
2024-02-23 move a big array outside of function scope to avoid crash
    [loragw_sx1302.c]
2024-02-26 document update: add info about how to install usb-to-bridge device driver under Windows
2024-02-28 switch to v2.1.0 pkt-fwd
2024-05-25 fix: allow redefining of SX1302_SPI_HOST
    this was problably overlooked during migration to new hal
    [loragw_spi.h]
2024-06-21 Check if POWER_EN_PIN is set
2024-06-21 Check if buttons exist before using
2024-06-25 Update platformio.ini for nodo board
    Add an env: for the board being sold by nodo-shop.nl
2024-06-27 replace all of 'uint32_t' to 'unsigned int'
    [loragw_cal.c, loragw_gps.c, loragw_gps.h]
2025-06-24 update README: add steps for run_me.sh to support esp32c3
2025-11-04 fix compile errors, now builds with esp-idf-v5.4.2
    [loragw_sx1302.c]
2025-11-07 fix a few compile warnings
    [loragw_gps.c, loragw_hal.c]
2026-06-09 fix time sync issue when pps signal lost for longer than a few minutes
    [loragw_gps.c, loragw_gps.h]
